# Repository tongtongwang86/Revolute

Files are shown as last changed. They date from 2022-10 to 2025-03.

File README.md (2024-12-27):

# Revolute
- nRF52833 Based Scroll wheel dial
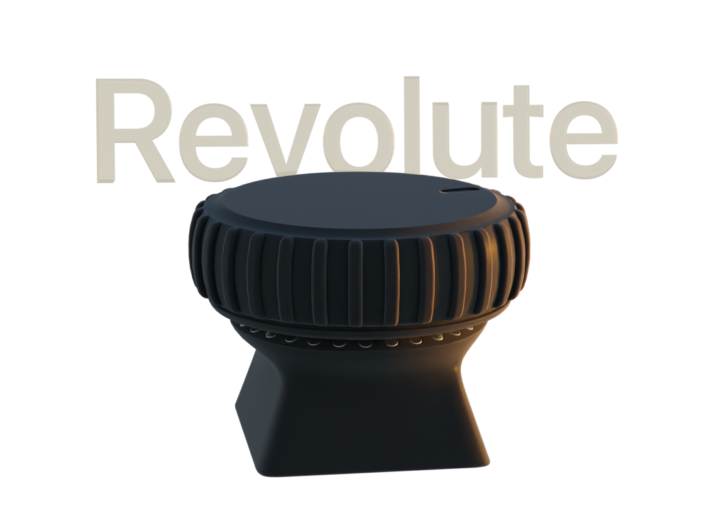
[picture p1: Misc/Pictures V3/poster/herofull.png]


<p align="center">
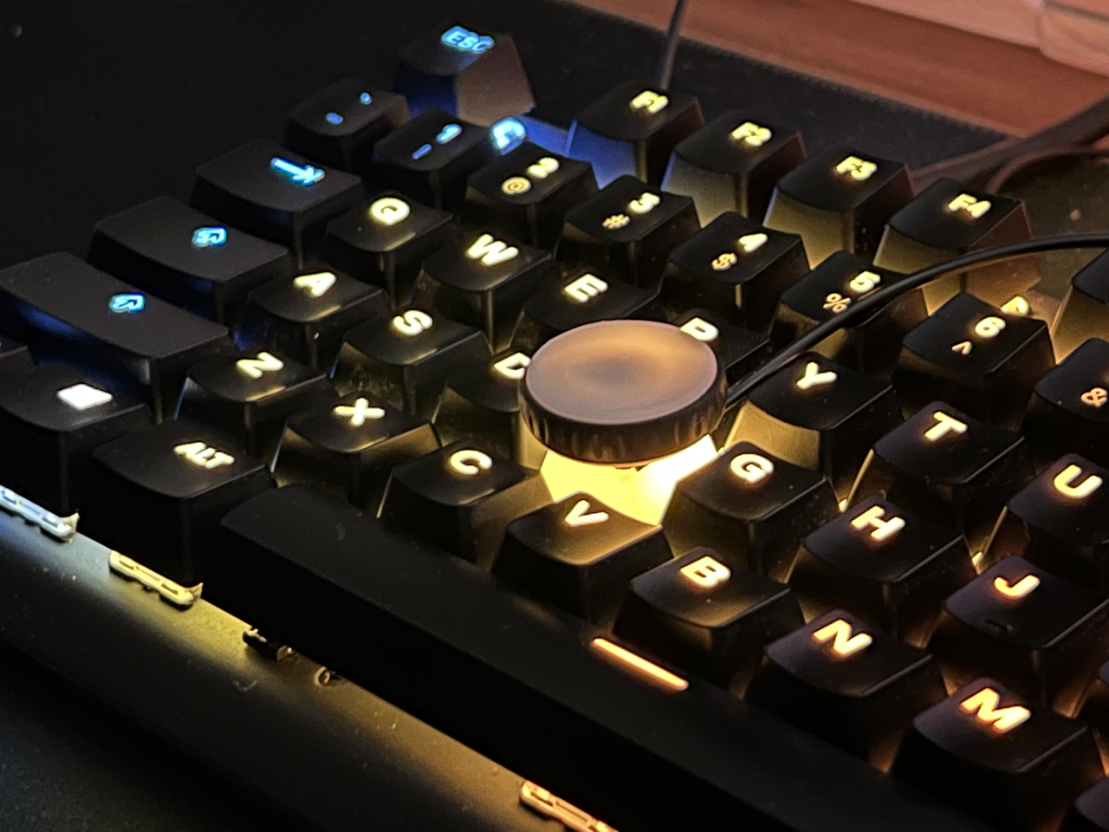
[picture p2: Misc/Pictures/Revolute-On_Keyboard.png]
    
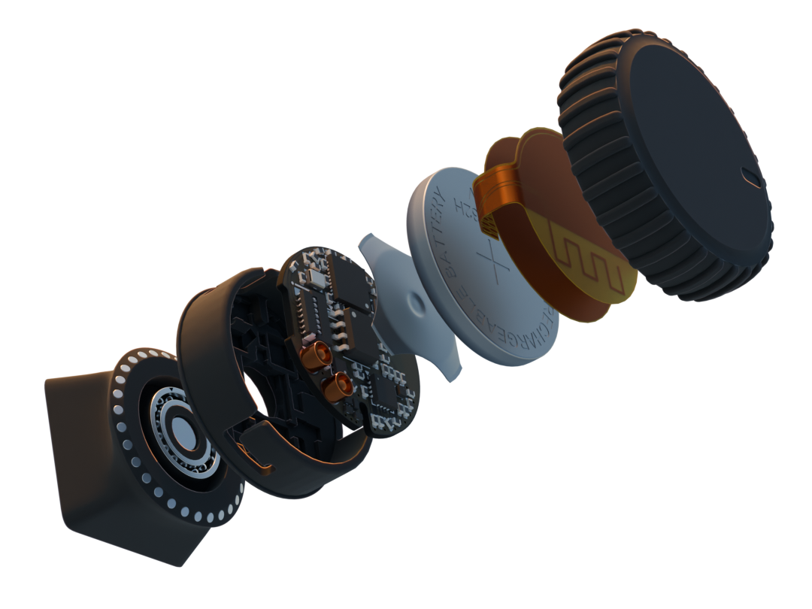
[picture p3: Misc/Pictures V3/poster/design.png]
    
</p>

## Introducing Revolute
 <a href="https://tongtonginc.com/revolute">Visit the product page website (Faster loading time, Interactive 3D Models, Demo Videos)</a>

### The Revolute is a scroll wheel/dial that aims to revolutionize the way we interact with complex software applications.

- Revolute currently simulate keyboard inputs, consumer controlls, mouse inputs.

- the actions and sensitivity of the wheel can be configured through the revolute configurator app that will be available for iOS, Macos and Windows devices that have bluetooth support.

- Configuratios done on revolute is persistently stored on device, which means that revolute can work on any device with Bluetooth and HID support.

- Revolute has a number of use cases and is not limited to: scrubbing through a timeline in a video editing app, changing the brush size in 3D/2D painting, smooth scrolling, volume controll, brightness control, media playback control, quickly pressing keys in short successions within games. if you get two you can bind each revolute axis to x and y of the cursor, making a etch a sketch

- Gamepad emulation is currently in development, which will allow you to use revolute within a wide range of mobile and console games.

## How the Revolute works

### Rotational inputs
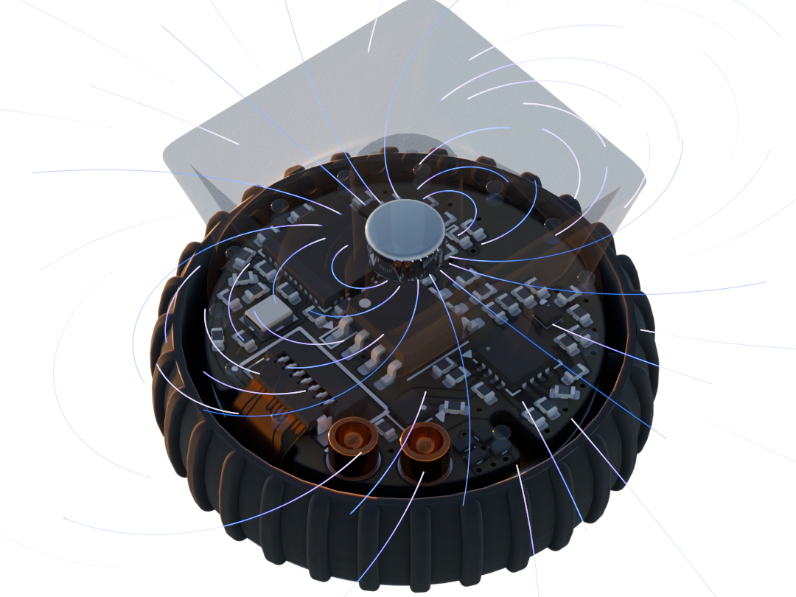
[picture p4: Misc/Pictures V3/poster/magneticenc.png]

- Revolute has gone through a number of iterations and currently uses the AS5600 magnetic encoder. It recordes the angle of a diametric magnet embedded within the base of the revolute, which the SoC will process and send bluetooth reports to the host device.

### BLE connection
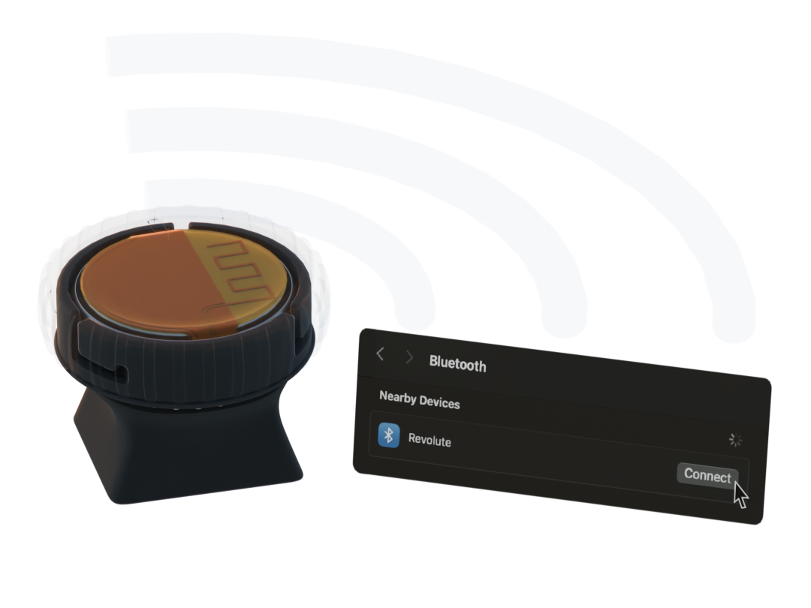
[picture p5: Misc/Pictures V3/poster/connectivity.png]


- Using BLE wireless connection we can have the Revolute connected to devices such as your computer, phone, or tablet using bluetooth. 
- By using the nRF52833 SoC and Zephyr RTOS, the Revolute is designed to maximize its power efficiency for bluetooth functionalities.

### Central button
- By pressing down on the Revolute, it powers on the device.
- After powering on the device, the button can also be configured to other actions based on your configurations
- Power it off by pressing and holding down on the button.

### Configuration
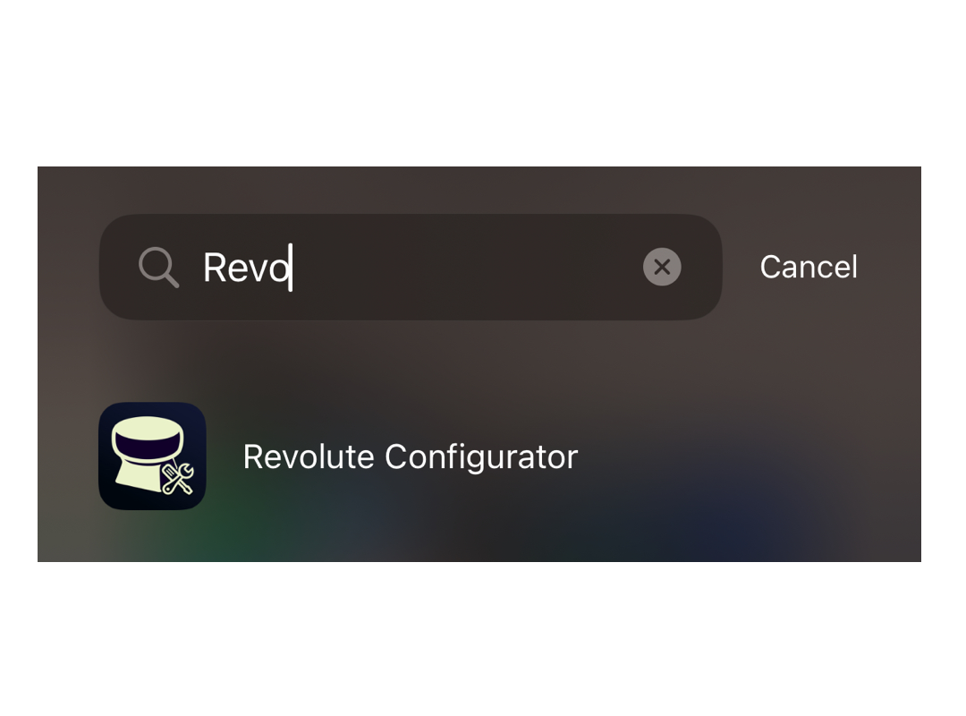
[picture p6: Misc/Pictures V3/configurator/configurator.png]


- As mentioned before, the Revolute's functionalities can be configured through the Revolute Configuration app that is currently in development
- Once you have made your changes to our configurations, they are then sent to the Revolute over bluetooth and stored locally on the SoC. allowing you to use the same configurations across different devices.

### Accessories 
- Revolute has a range of existing accessories that allow you to use it within different use cases

- Key attachment 
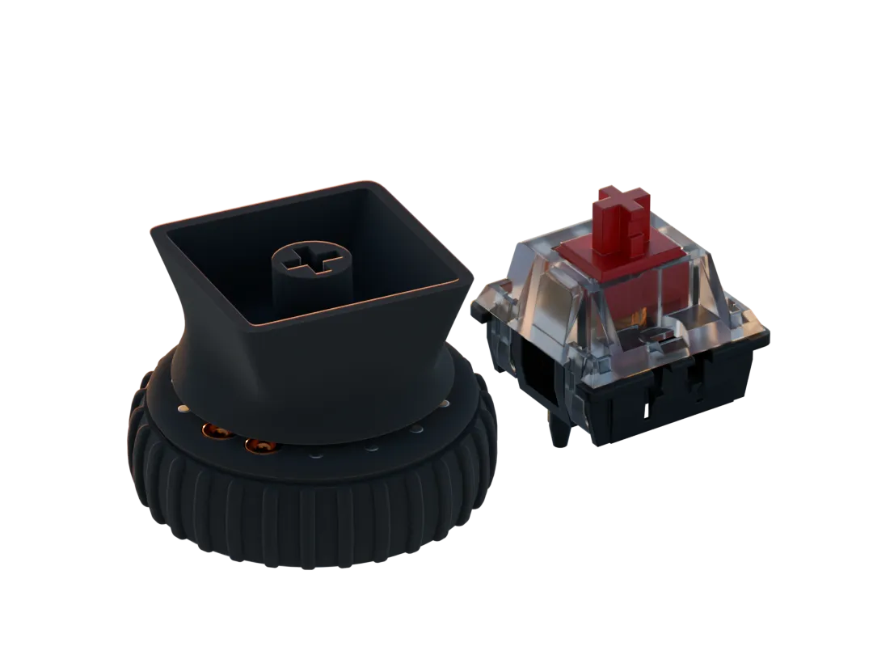
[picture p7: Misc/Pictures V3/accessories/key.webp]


- Adhesive/magnetic attachment
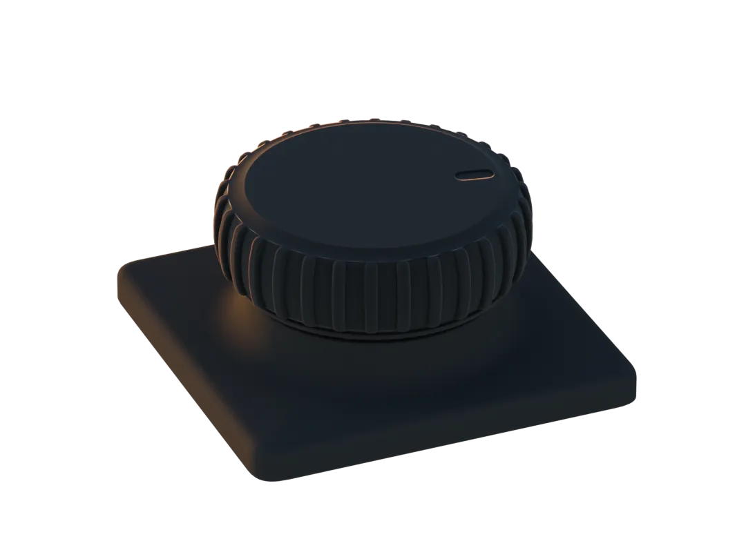
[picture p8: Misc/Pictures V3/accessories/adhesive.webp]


- Phone attachment 
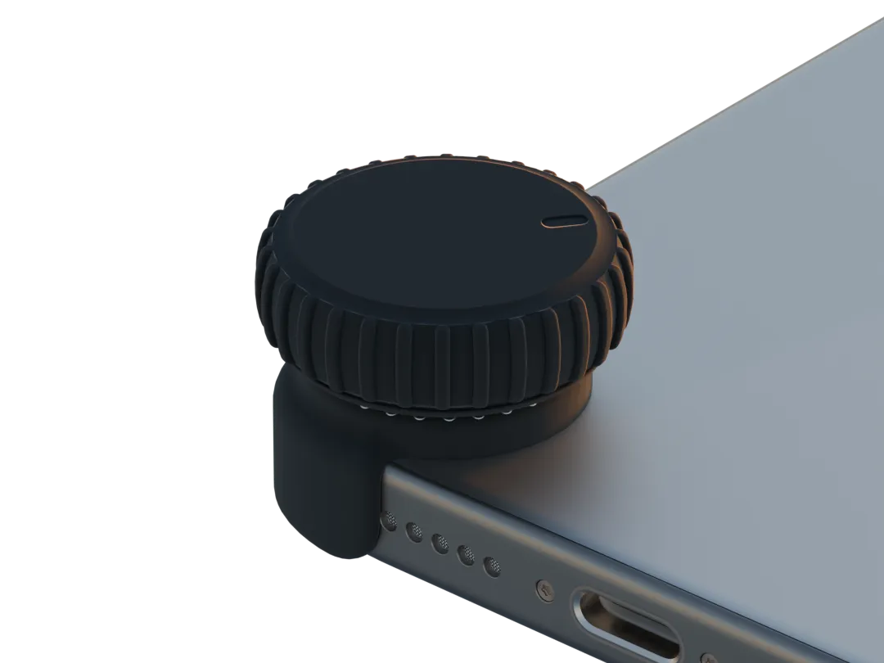
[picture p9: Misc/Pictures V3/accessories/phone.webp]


- Revo-Pod charges the revolute and is a place to store your attachments.
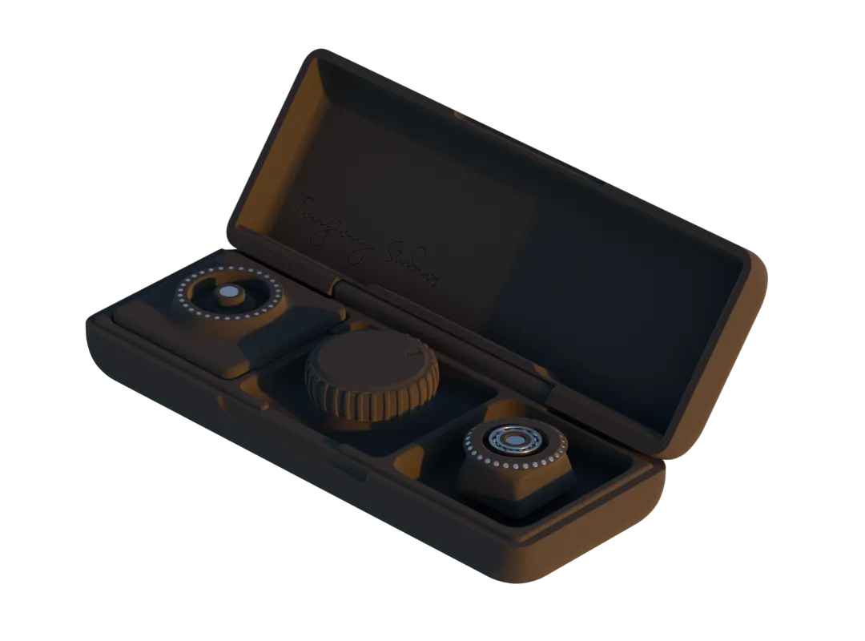
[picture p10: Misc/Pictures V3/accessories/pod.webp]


- The attachment can be hot swapped with a common bearing interface.
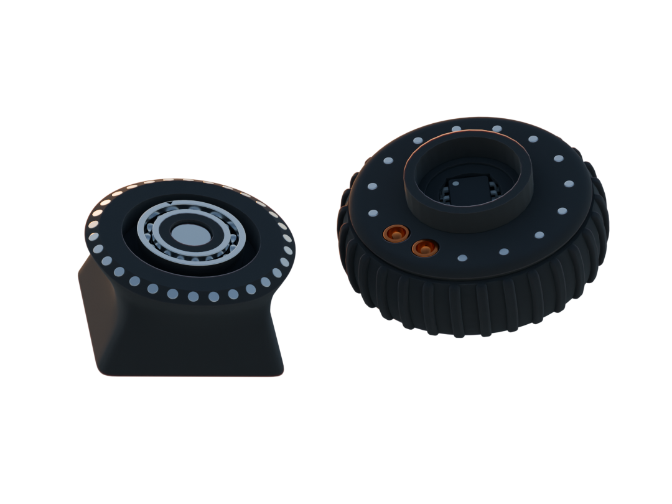
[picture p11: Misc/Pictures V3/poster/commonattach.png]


### Charging and Battery Replacement
- For this device to be wireless, the Revolute is comprised of a 70Mah li-Ion rechargable coin cell battery (LIR2032H)
- The Revolute uses the BQ24075-RGT charger ic and BQ27441-G1 fuel gauge, both by Texas Instruments, for charging, monitoring, and managing the battery that powers the system.
- To charge the Revolute, simply take your Revopod and mount it in the pod and have the two pogopins aligned with the receptors on the wheel.
- To replace the battery, simply flip the Revolute over, press it down until you feel the central button being completely pressed down, and twist it clockwise and you should be able to have the entire Revolute disassembled. From there, simply place a new battery in and reverse the steps of how you disassembled it after your align the cap with the body chassis.

### *Gyro mouse
- With the LSM6DS3 gyroscope accelerometer incorporated in on the Revolute, you can configure it to control the movements of your cursor by moving the Revolute around.
- This feature is still in development and will be finalized shortly in our next firmware updates

## How this repo works
- PCB hardware files are in the folder /Hardware
- 3D printed part files are stored in the folder /3D Prints
- Latest firmware is hosted on the repo <a href="https://github.com/tongtongwang86/revolute-firmware-ci">"revolute-firmware-ci"</a>
- There is also a wired version of the revolute in this repo

## Get your own Revolute
- Revolute is still in development and will be ready soon

 - <a href="https://tongtonginc.com/revolute">For more information head to the product page</a>

- Feel free to DM us if you have any questions or requests

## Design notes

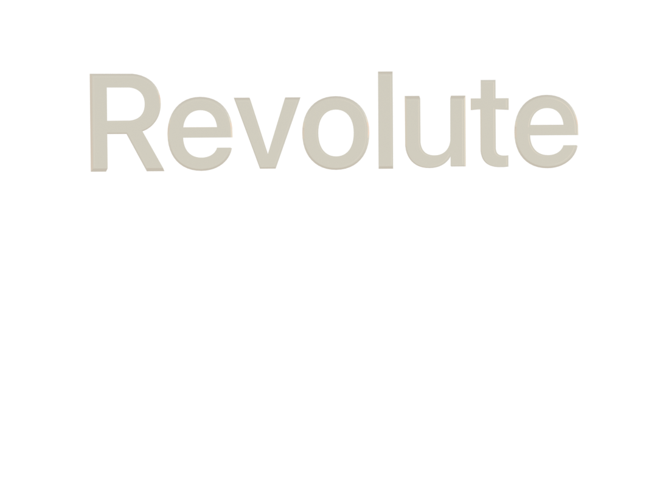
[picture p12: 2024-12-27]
Misc/Pictures V3/poster/hero.png

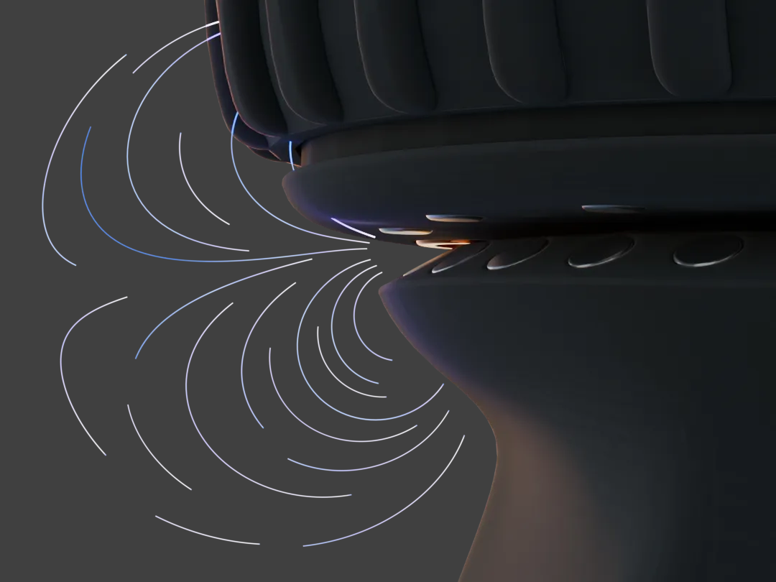
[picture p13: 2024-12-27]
Misc/Pictures V3/poster/magtick.webp

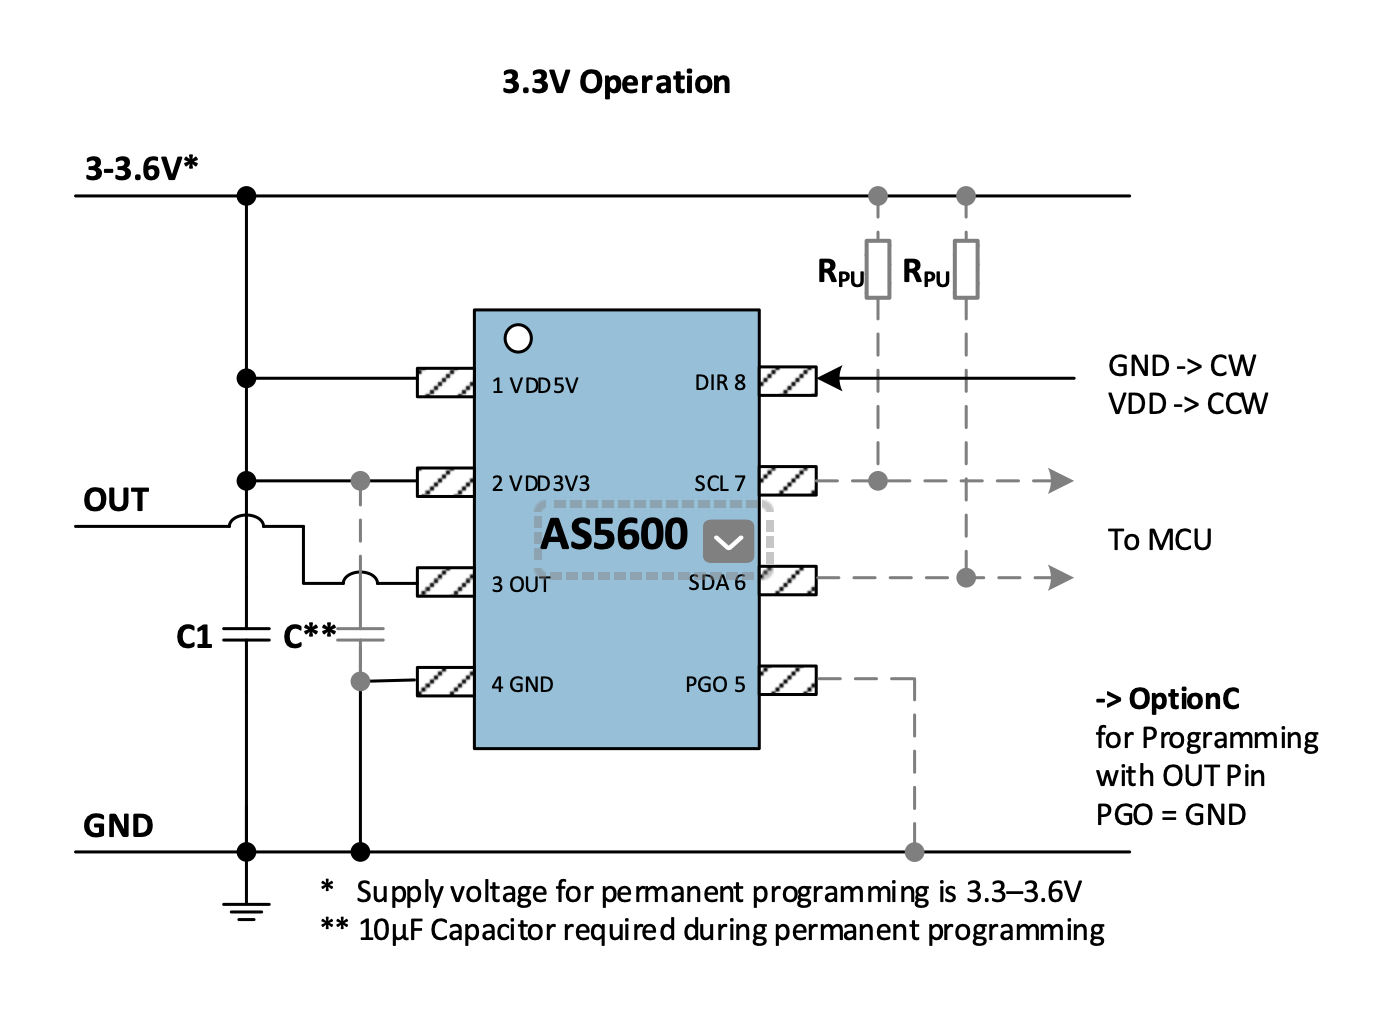
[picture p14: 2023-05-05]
Hardware/Wired/TopPCB/Screenshot 2023-05-04 at 10.35.59 PM.png

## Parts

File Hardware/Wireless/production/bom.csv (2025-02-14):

Designator | Footprint | Quantity | Value | LCSC Part #
D1 | 0402 | 1 | BLUE

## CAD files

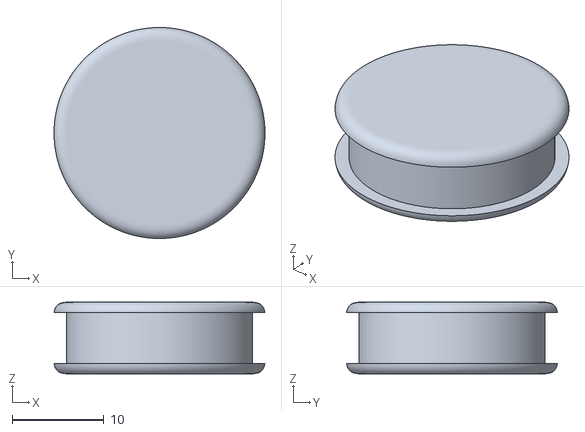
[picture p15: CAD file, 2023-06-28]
3D Prints/V2.1/Cap.stl
23.0 x 23.0 x 7.80

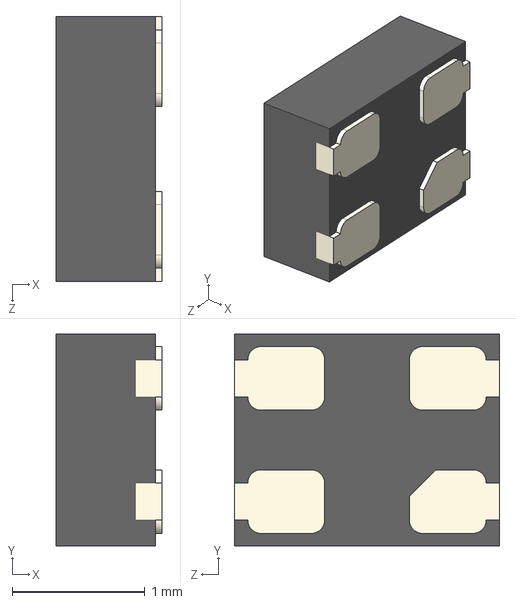
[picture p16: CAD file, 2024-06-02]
Hardware/Debugger/3D/QFN_2016_4pins.STEP
0.8 x 1.60 x 2.00 mm

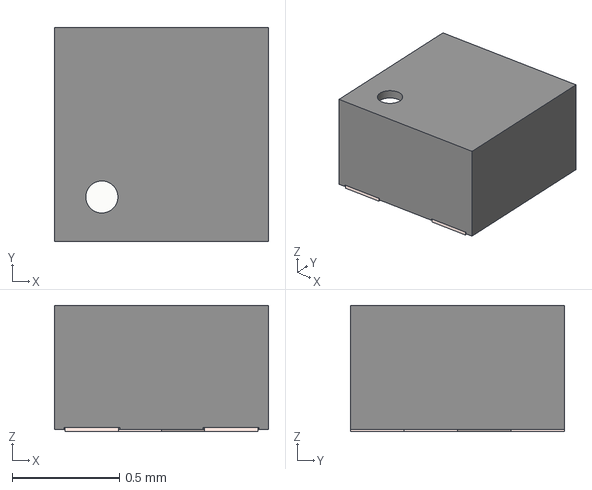
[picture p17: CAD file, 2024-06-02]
Hardware/Debuggerbmp/3D/TDFN-4 v1.step
1.00 x 1.00 x 0.59 mm

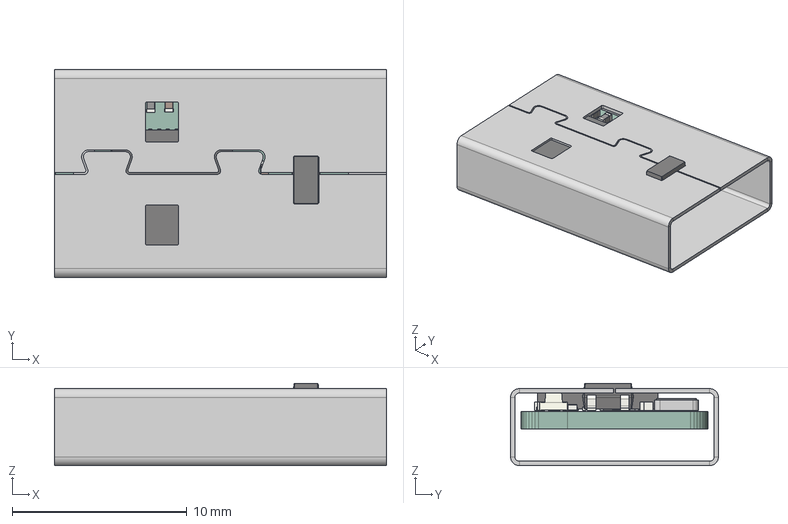
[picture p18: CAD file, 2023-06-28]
Hardware/Wired/MainPCB/revo.step
19.0 x 11.9 x 4.70 mm
PCB

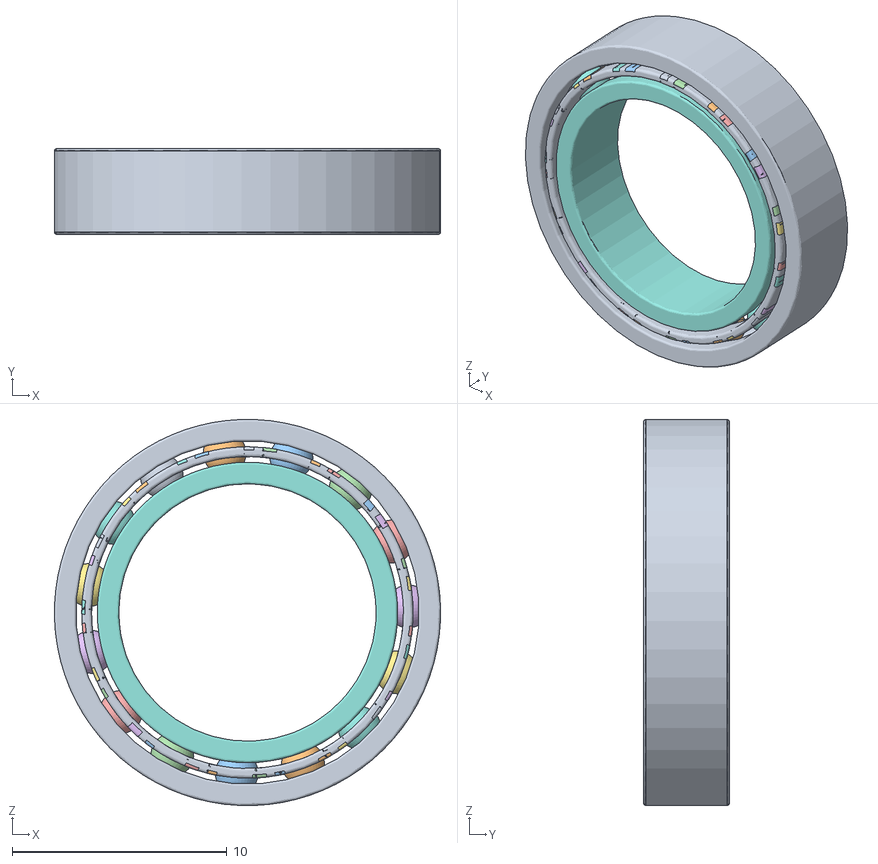
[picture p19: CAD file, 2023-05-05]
Hardware/Wired/TopPCB/Ball_Bearing_Parametric v9 v6.obj
18.0 x 4.00 x 18.0
Outer Ring
Ball Bearings
Ball Bearings (1)
Ball Bearings (2)
Ball Bearings (3)
Ball Bearings (4)
Ball Bearings (5)
Ball Bearings (6)
Ball Bearings (7)
Ball Bearings (8)
Race
Ball race clip outer cylinder
Ball race clip outer cylinder (1)
Ball race clip outer cylinder (1):1
Ball race clip outer cylinder (1) (2)
Ball race clip outer cylinder (1) (3)
Ball race clip outer cylinder (4)
Ball race clip outer cylinder (5)
Ball race clip outer cylinder (1) (6)
Ball race clip outer cylinder (1) (7)
Ball race clip outer cylinder (1) (8)
Ball race clip outer cylinder (1) (9)
Ball race clip outer cylinder (10)
Ball race clip outer cylinder (11)
Ball race clip outer cylinder (12)
Ball race clip outer cylinder (13)
Ball race clip outer cylinder (14)
Ball race clip outer cylinder (1) (1)
Ball race clip outer cylinder (2)
Ball race clip outer cylinder (3)
Ball race clip outer cylinder (1) (4)
Ball race clip outer cylinder (1) (5)
Ball race clip outer cylinder (6)
Ball race clip outer cylinder (7)
Ball race clip outer cylinder (8)
Ball race clip outer cylinder (9)
Ball race clip outer cylinder (1) (10)
Ball race clip outer cylinder (1) (11)
Ball race clip outer cylinder (1) (12)
Ball race clip outer cylinder (1) (13)
Ball race clip outer cylinder (1) (14)
Inner Ring

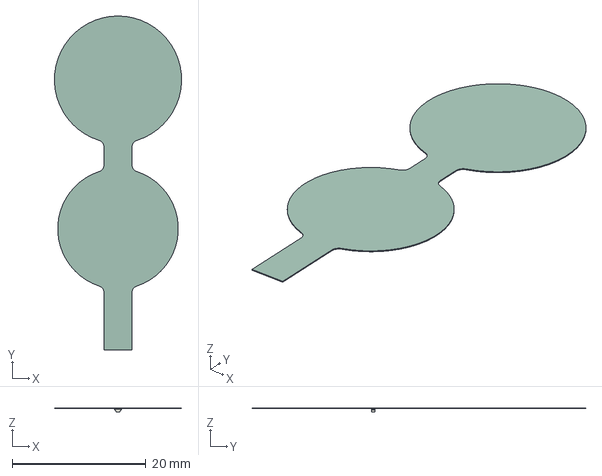
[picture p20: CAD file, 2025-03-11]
Hardware/Wireless/flex3kicad_pcb.step
19.0 x 49.9 x 0.656 mm
LED_0402_1005Metric
_autosave-flex3kicad_pcb_PCB

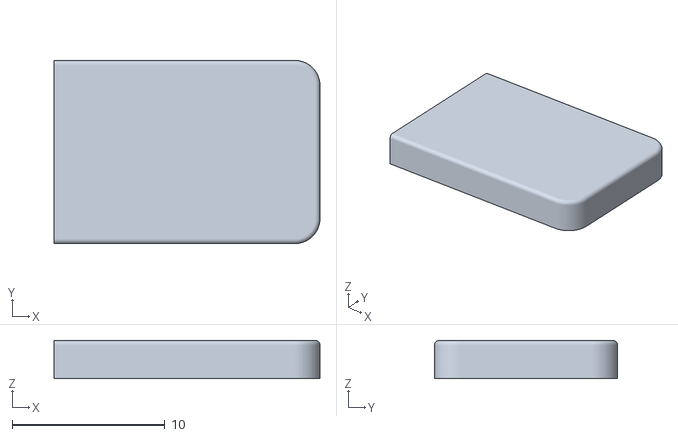
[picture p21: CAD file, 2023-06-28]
3D Prints/V2.1/pcbtray.stl
17.4 x 12.0 x 2.50

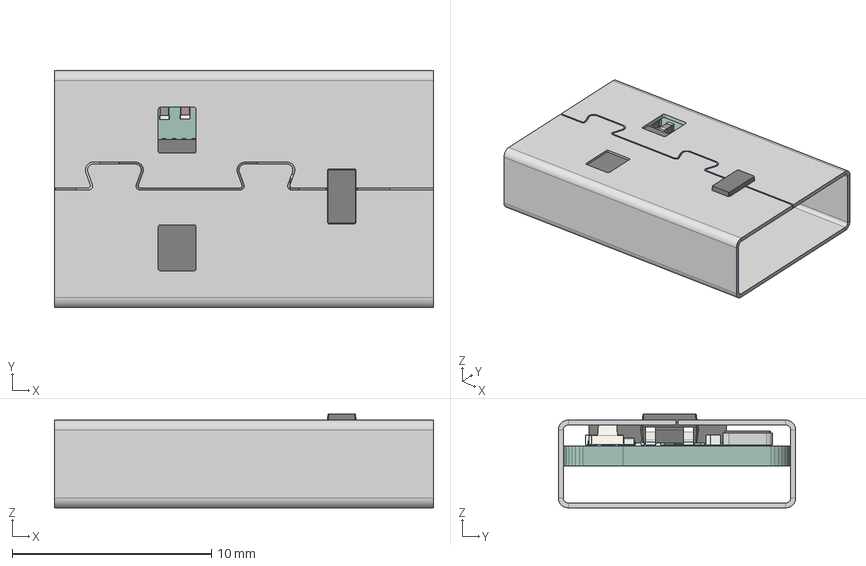
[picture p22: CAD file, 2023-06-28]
Hardware/Wired/MainPCB/rev.step
19.0 x 11.9 x 4.70 mm
PCB

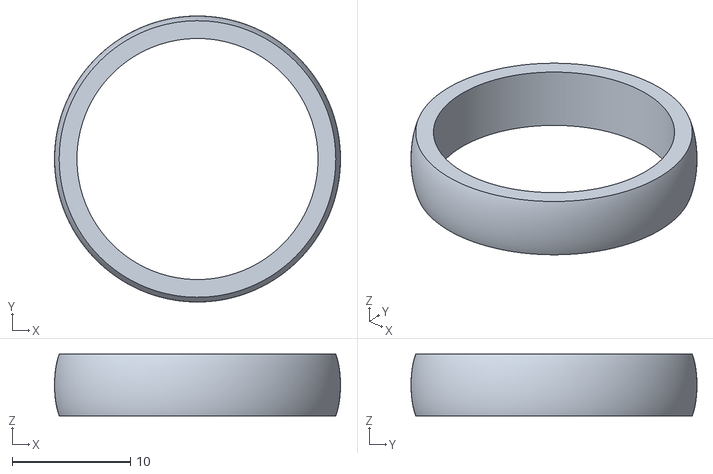
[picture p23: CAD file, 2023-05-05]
Hardware/Wired/TopPCB/rubber.stl
24.2 x 24.2 x 5.20

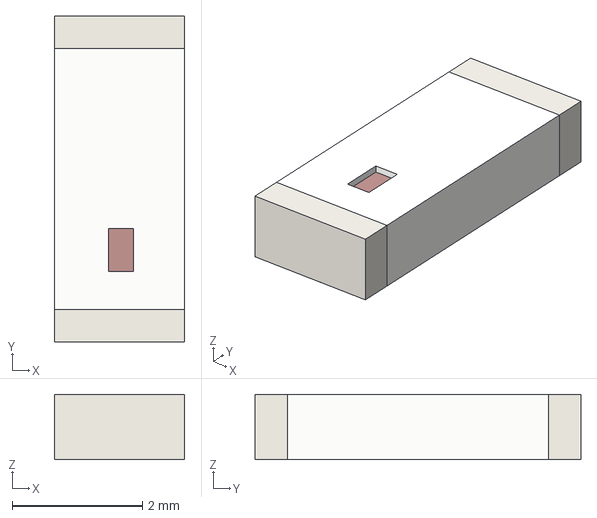
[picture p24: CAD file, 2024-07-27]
Hardware/Wireless/3d/Chip Antenna.step
2.00 x 5.00 x 1.00 mm

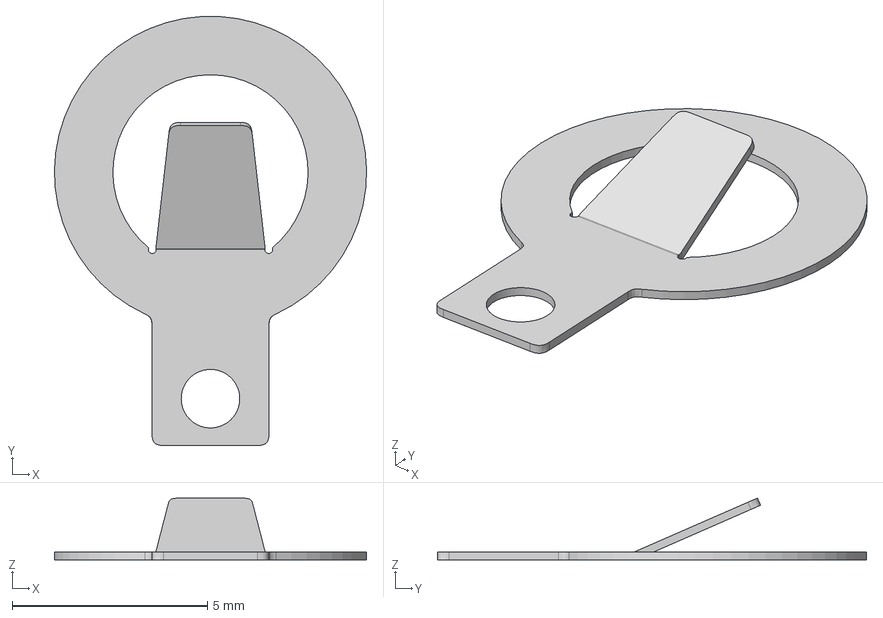
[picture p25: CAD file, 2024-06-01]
Hardware/Debugger/3D/BatteryBase.step
8.00 x 11.0 x 1.59 mm

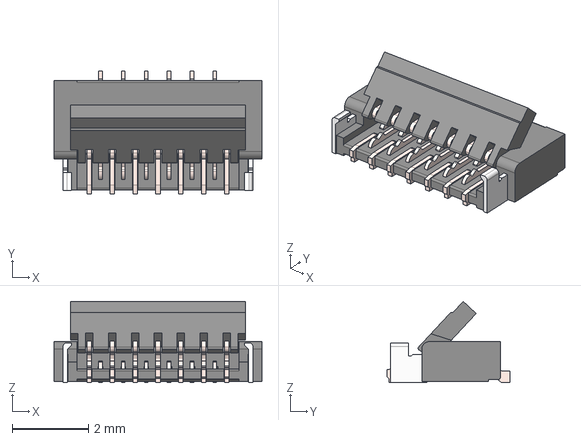
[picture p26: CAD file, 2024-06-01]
Hardware/Debuggerbmp/3D/FPC ZIF.step
5.46 x 3.23 x 2.13 mm

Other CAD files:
3D Prints/V1/Revolute_Wheel.stl
3D Prints/V2/Base.stl
3D Prints/V2/Cap.stl
Hardware/Debugger/3D/256Mbit GD25Q.step
Hardware/Debugger/3D/32MHZ Clock v1.step
Hardware/Debugger/3D/APDS-9960.step
Hardware/Debugger/3D/Antenna.step
Hardware/Debugger/3D/BK13C06-10DP2-0.35V_3D_STP.stp
Hardware/Debugger/3D/BK13C06-10DS2-0.35V_3D_STP.stp
Hardware/Debugger/3D/Battery v2.step
Hardware/Debugger/3D/Battery2 v1.step
Hardware/Debugger/3D/Button.step
Hardware/Debugger/3D/Crystal 2 v0.step
Hardware/Debugger/3D/GateronHotswap v3.step
Hardware/Debugger/3D/Humidity.step
Hardware/Debugger/3D/Inductor v1.step
Hardware/Debugger/3D/KailhChocV2.step
Hardware/Debugger/3D/LedV2 v4.step
Hardware/Debugger/3D/NRF52832-CIAA-R.step
Hardware/Debugger/3D/Pdmmic.step
Hardware/Debugger/3D/SW_Hotswap_Kailh_Choc_v1.stp
Hardware/Debugger/3D/USB - C inboard.step
Hardware/Debugger/3D/USB2 v3.step
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

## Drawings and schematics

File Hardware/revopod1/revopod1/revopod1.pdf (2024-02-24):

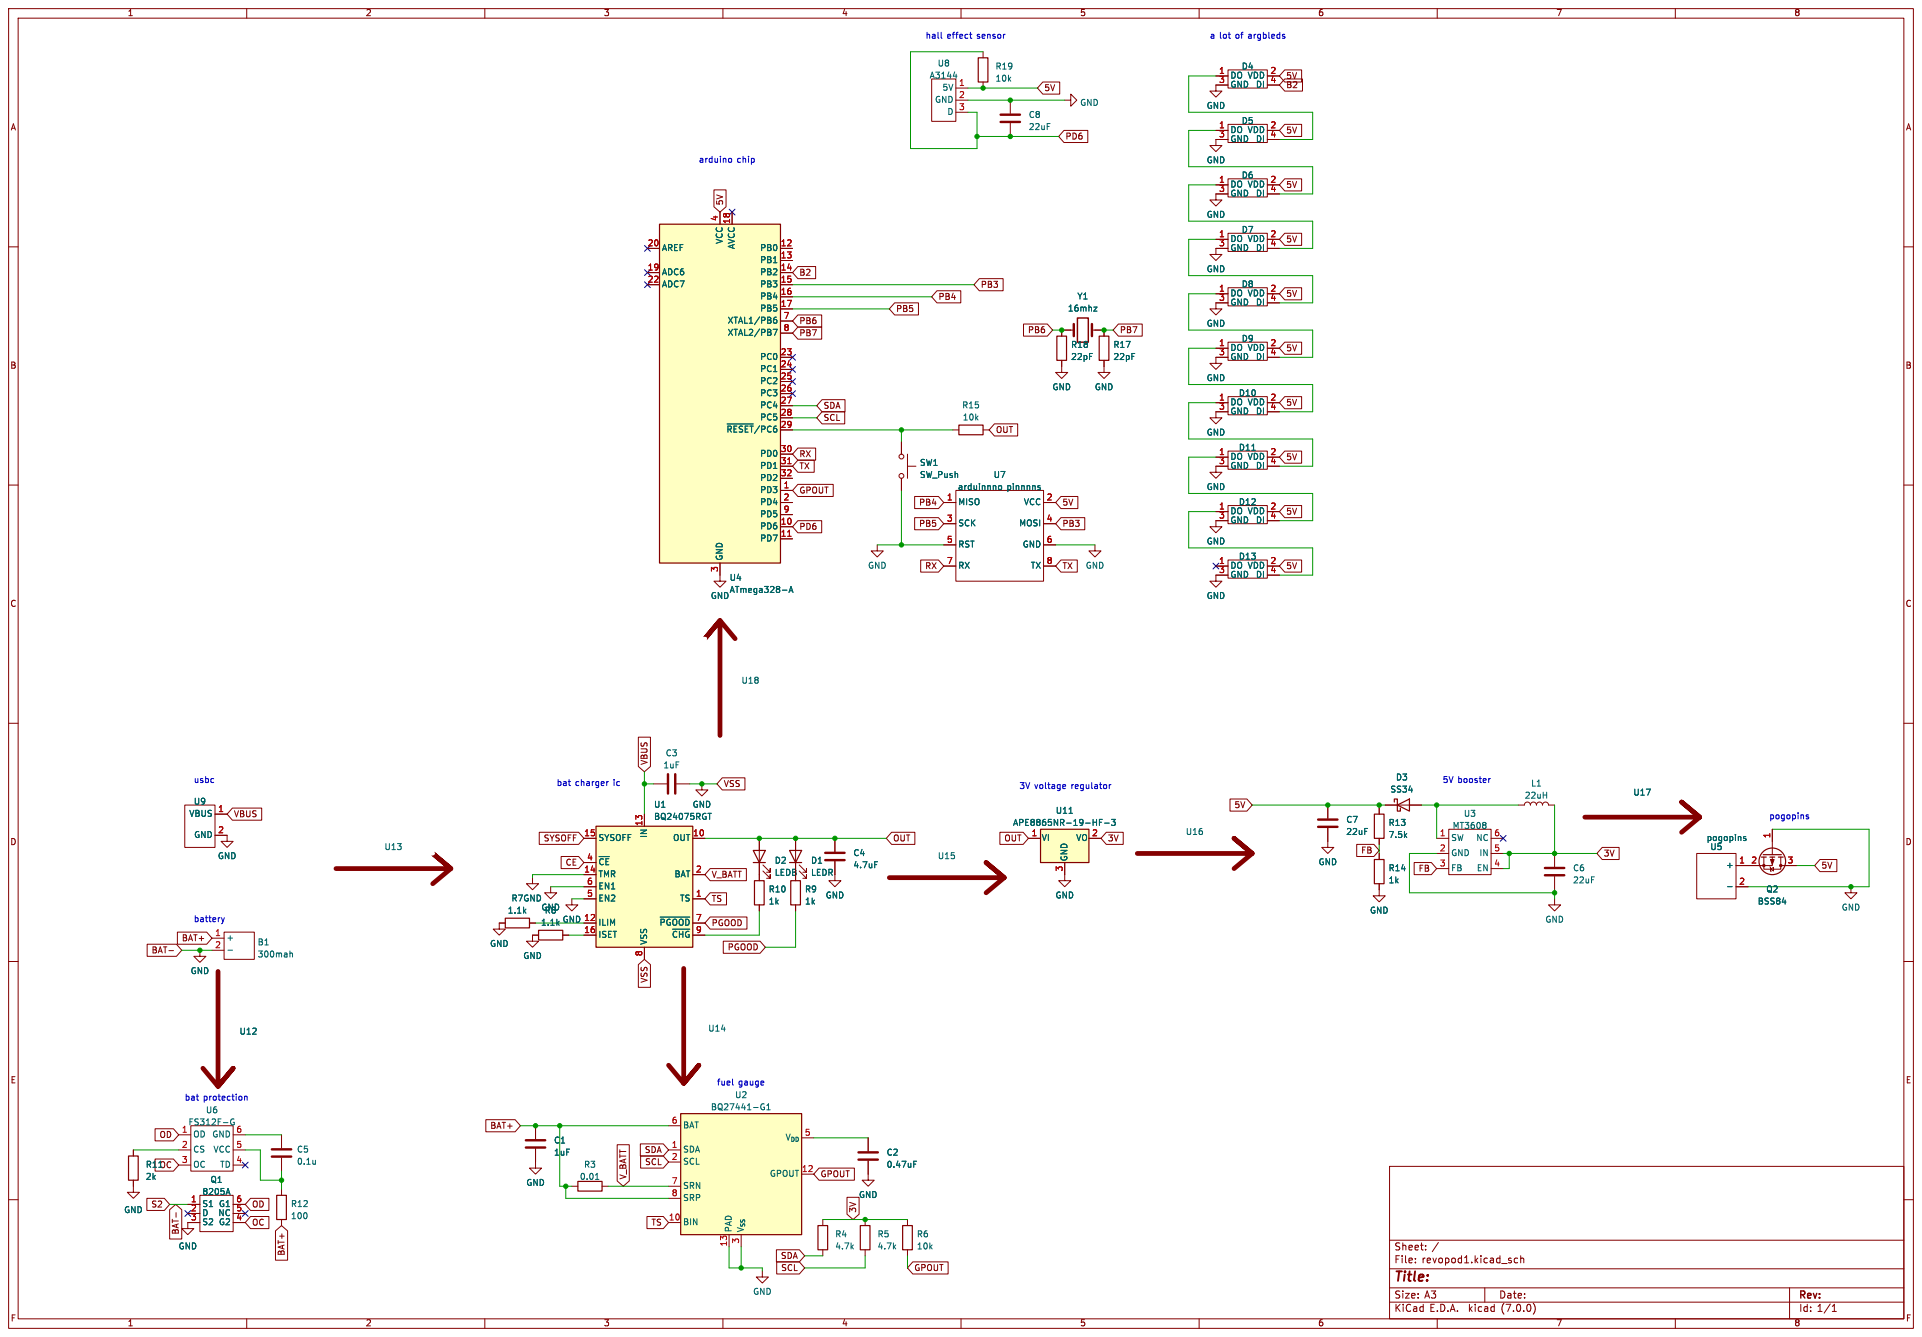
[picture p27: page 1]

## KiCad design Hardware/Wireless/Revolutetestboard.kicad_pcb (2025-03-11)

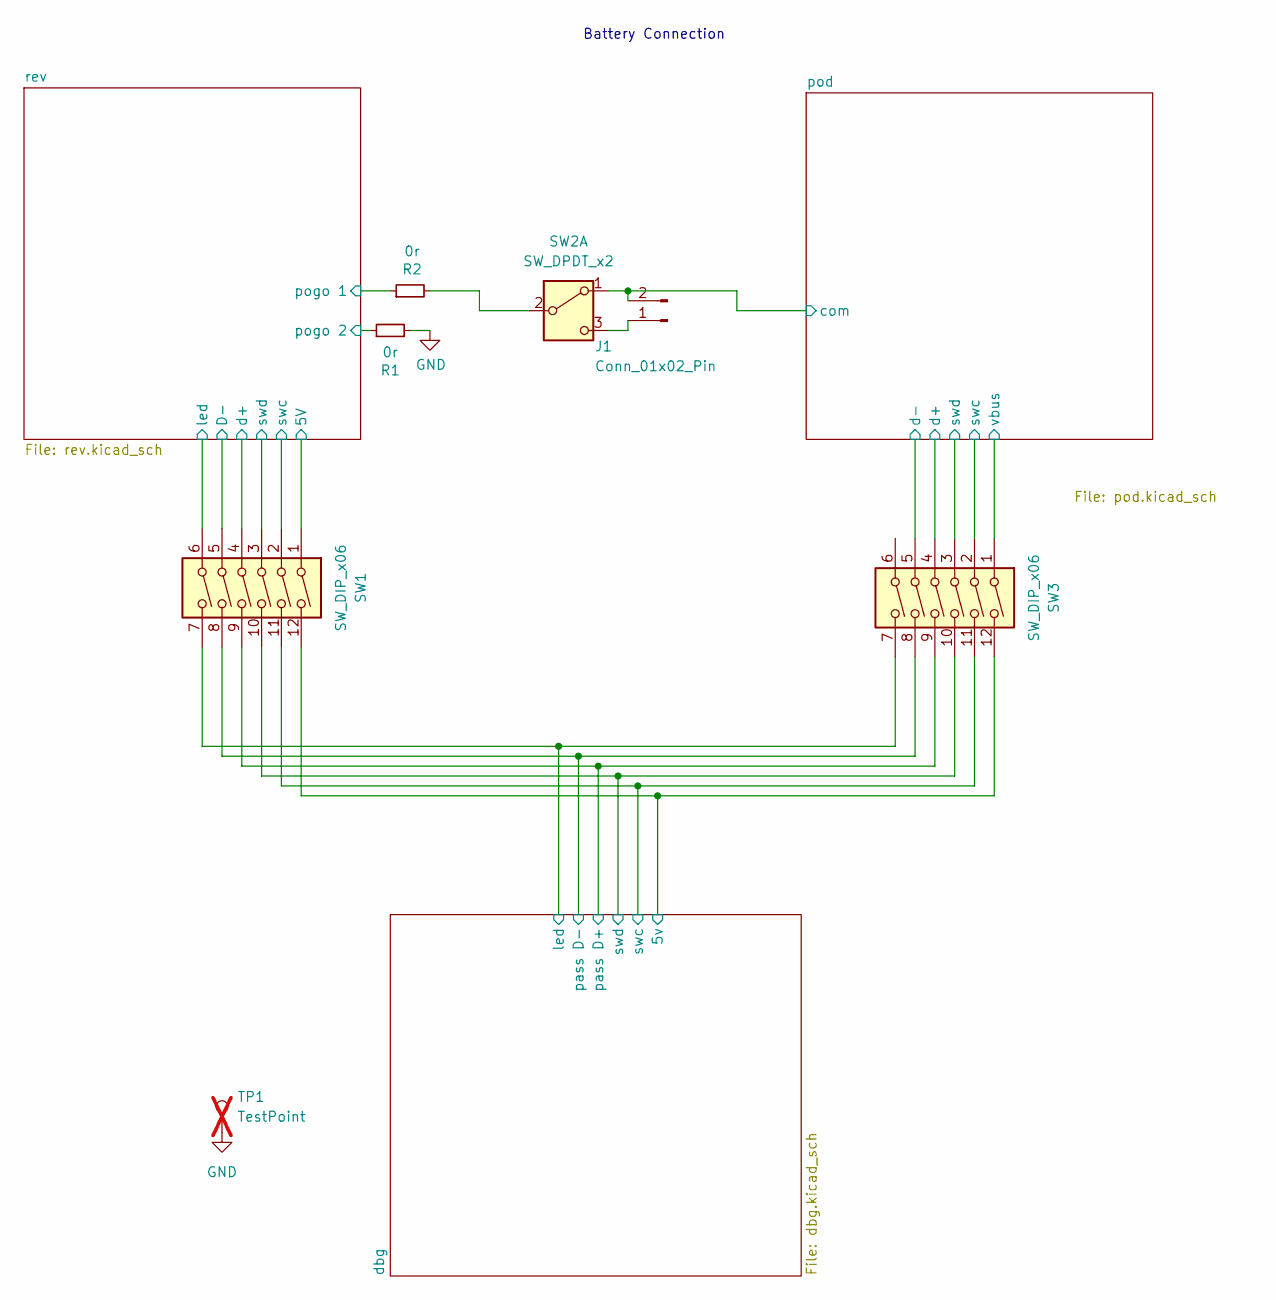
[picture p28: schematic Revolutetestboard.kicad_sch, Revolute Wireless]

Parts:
J1: Conn_01x02_Pin; PinHeader_1x02_P2.54mm_Vertical
R1, R2: 0r; 0402
SW1, SW3: SW_DIP_x06; SW_DIP_SPSTx06_Slide_Copal_CHS-06B_W7.62mm_P1.27mm
SW2: SW_DPDT_x2; MST-12C05 SLIDEBUTTON
TP1: TestPoint; TestPoint_Pad_D1.0mm; not fitted

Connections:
5V(2): SW1.12, SW3.12; also elsewhere on the board
/dbg/USBDM2: SW1.8, SW3.8; also elsewhere on the board
/dbg/USBDP2: SW1.9, SW3.9; also elsewhere on the board
/dbg/swc: SW1.11, SW3.11; also elsewhere on the board
/dbg/swd: SW1.10, SW3.10; also elsewhere on the board
/pod/COM: J1.2, SW2.1 (A); also elsewhere on the board
/pod/D+: SW3.4; also elsewhere on the board
/pod/D-: SW3.5; also elsewhere on the board
/pod/VBUS: SW3.1; also elsewhere on the board
/pod/swc: SW3.2; also elsewhere on the board
/pod/swd: SW3.3; also elsewhere on the board
/rev/+: R1.1; also elsewhere on the board
/rev/-: R2.1; also elsewhere on the board
/rev/D+: SW1.4; also elsewhere on the board
/rev/D-: SW1.5; also elsewhere on the board
/rev/FLEX_LED: SW1.6; also elsewhere on the board
/rev/VBUS: SW1.1; also elsewhere on the board
/rev/swc: SW1.2; also elsewhere on the board
/rev/swd: SW1.3; also elsewhere on the board
GND: R1.2, TP1.1; also elsewhere on the board
unnamed: J1.1, SW2.3 (C)
unnamed: R2.2, SW2.2 (B)
led: SW1.7, SW3.7; also elsewhere on the board

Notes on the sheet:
Battery Connection

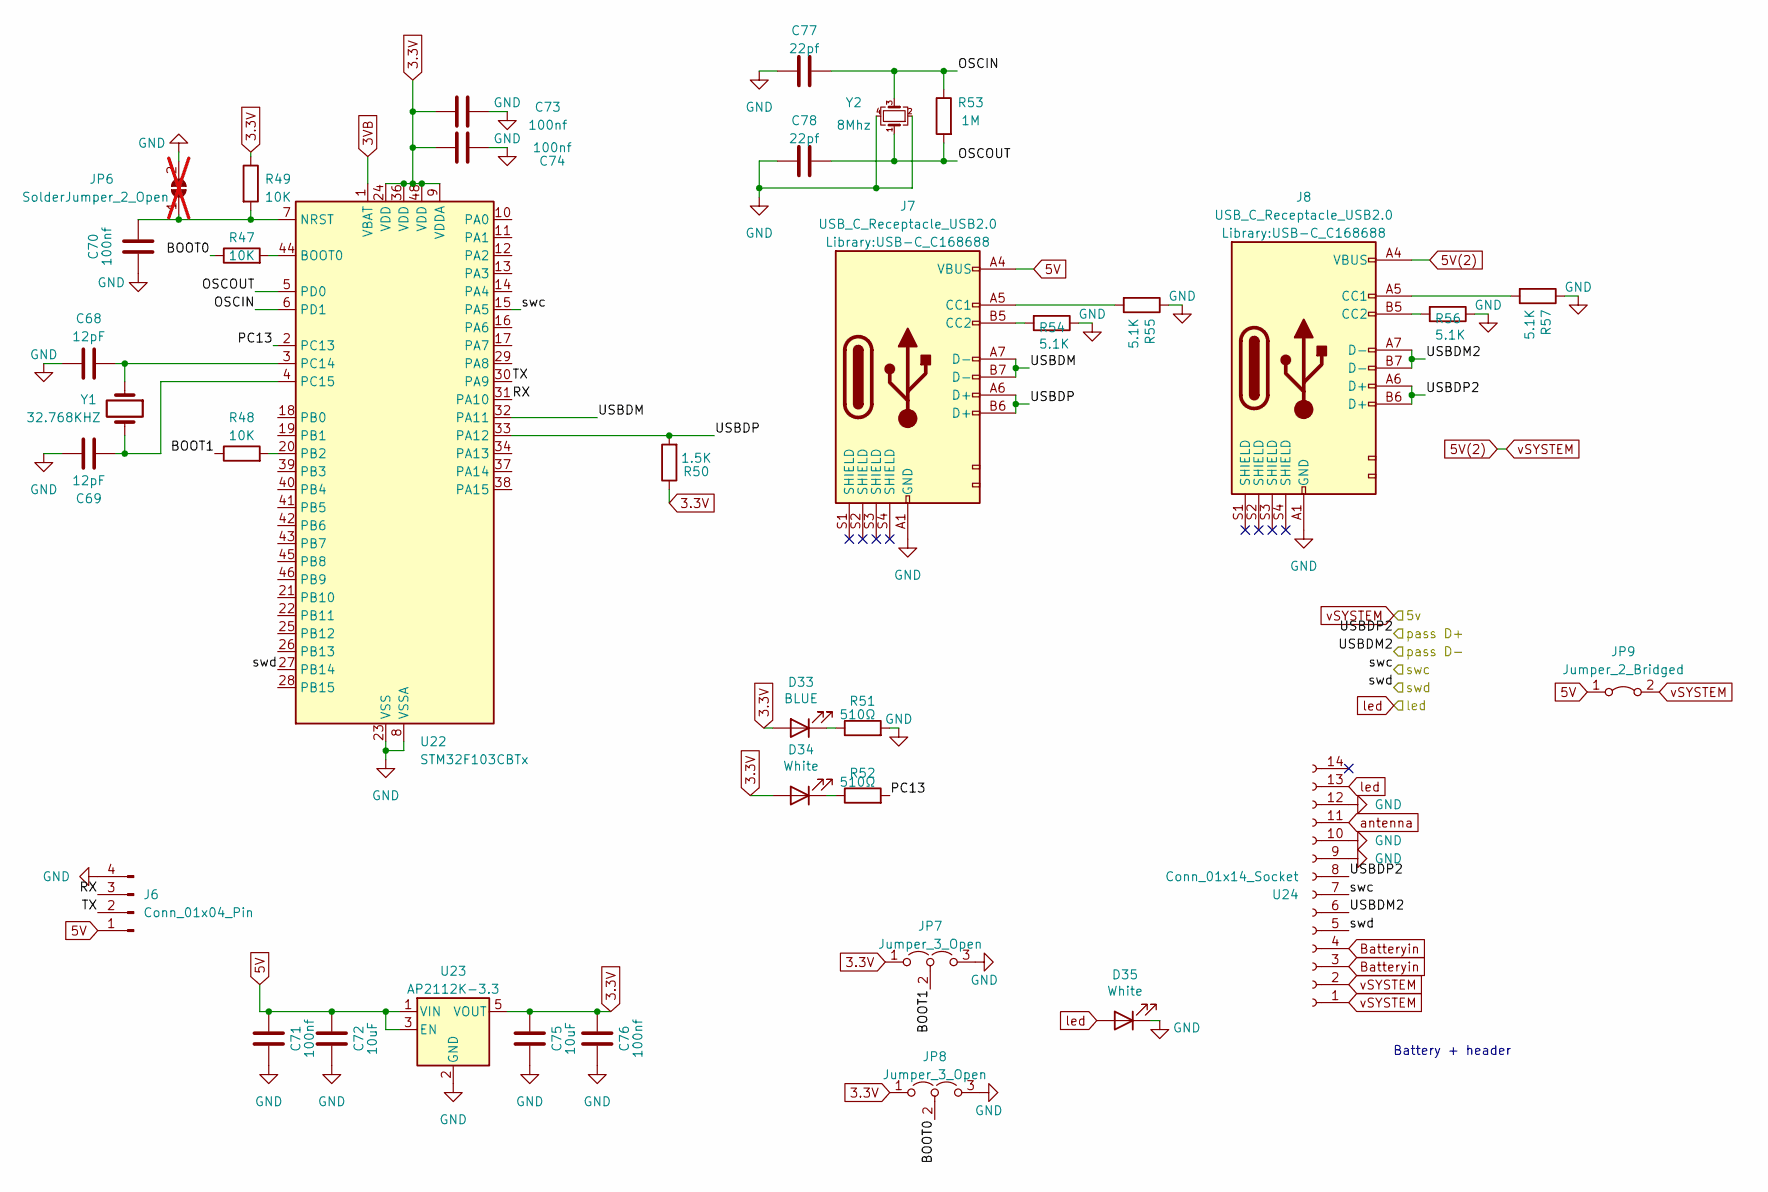
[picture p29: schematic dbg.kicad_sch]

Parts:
C68, C69: 12pF; 0402
C70, C71, C73, C74, C76: 100nf; 0402
C72, C75: 10uF; 0402
C77, C78: 22pf; 0402
D33: BLUE; LED_0402_1005Metric
D34, D35: White; LED_0402_1005Metric
J6: Conn_01x04_Pin; PinHeader_1x04_P1.27mm_Vertical
J7, J8: USB_C_Receptacle_USB2.0; USB-C_C168688
JP6: SolderJumper_2_Open; SolderBridge; not fitted
JP7, JP8: Jumper_3_Open; SolderJumper-3_P1.3mm_Open_RoundedPad1.0x1.5mm
JP9: Jumper_2_Bridged; SolderJumper-2_P1.3mm_Bridged_RoundedPad1.0x1.5mm
R47, R48, R49: 10K; 0402
R50: 1.5K; R_0402_1005Metric
R51, R52: 510Ω; R_0402_1005Metric
R53: 1M; R_0402_1005Metric
R54, R55, R56, R57: 5.1K; R_0402_1005Metric
U22: STM32F103CBTx; LQFP-48_7x7mm_P0.5mm
U23: AP2112K-3.3; SOT-23-5
U24: Conn_01x14_Socket; FPC
Y1: 32.768KHZ; Crystal_SMD_3215-2Pin_3.2x1.5mm
Y2: 8Mhz; Crystal_SMD_3225-4Pin_3.2x2.5mm

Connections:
3.3V: C73.2, C74.2, C75.2, C76.2, D33.2 (A), D34.2 (A), JP7.1 (A), JP8.1 (A), R49.1, R50.1, U22.9 (VDDA), U22.24 (VDD), U22.36 (VDD), U22.48 (VDD), U23.5 (VOUT)
3VB: U22.1 (VBAT)
5V: C71.2, C72.2, J6.1, J7.A4 (VBUS), JP9.1 (A), U23.1 (VIN), U23.3 (EN)
5V(2): J8.A4 (VBUS), JP9.2 (B), U24.1, U24.2; also elsewhere on the board
/dbg/BOOT0: JP8.2 (C), R47.1
/dbg/BOOT1: JP7.2 (C), R48.1
/dbg/OSCIN: C77.2, R53.1, U22.6 (PD1), Y2.3
/dbg/OSCOUT: C78.2, R53.2, U22.5 (PD0), Y2.1
/dbg/PC13: R52.2, U22.2 (PC13)
/dbg/RX: J6.3, U22.31 (PA10)
/dbg/TX: J6.2, U22.30 (PA9)
/dbg/USBDM: J7.A7 (D-), J7.B7 (D-), U22.32 (PA11)
/dbg/USBDM2: J8.A7 (D-), J8.B7 (D-), U24.6; also elsewhere on the board
/dbg/USBDP: J7.A6 (D+), J7.B6 (D+), R50.2, U22.33 (PA12)
/dbg/USBDP2: J8.A6 (D+), J8.B6 (D+), U24.8; also elsewhere on the board
/dbg/swc: U22.15 (PA5), U24.7; also elsewhere on the board
/dbg/swd: U22.27 (PB14), U24.5; also elsewhere on the board
Batteryin: U24.3, U24.4
GND: C68.1, C69.2, C70.1, C71.1, C72.1, C73.1, C74.1, C75.1, C76.1, C77.1, C78.1, D35.1 (K), J6.4, J7.A1 (GND), J8.A1 (GND), JP6.2 (B), JP7.3 (B), JP8.3 (B), R51.2, R54.1, R55.1, R56.1, R57.1, U22.8 (VSSA), U22.23 (VSS), U22.35 (VSS), U22.47 (VSS), U23.2 (GND), U24.9, U24.10, U24.12, Y2.2, Y2.4; also elsewhere on the board
unnamed: D33.1 (K), R51.1
unnamed: D34.1 (K), R52.1
unnamed: J7.A5 (CC1), R55.2
unnamed: J7.B5 (CC2), R54.2
unnamed: J8.A5 (CC1), R57.2
unnamed: J8.B5 (CC2), R56.2
unnamed: C70.2, JP6.1 (A), R49.2, U22.7 (NRST)
unnamed: R47.2, U22.44 (BOOT0)
unnamed: R48.2, U22.20 (PB2)
unnamed: C68.2, U22.3 (PC14), Y1.1
unnamed: C69.1, U22.4 (PC15), Y1.2
antenna: U24.11
led: D35.2 (A), U24.13; also elsewhere on the board

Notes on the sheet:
Battery + header

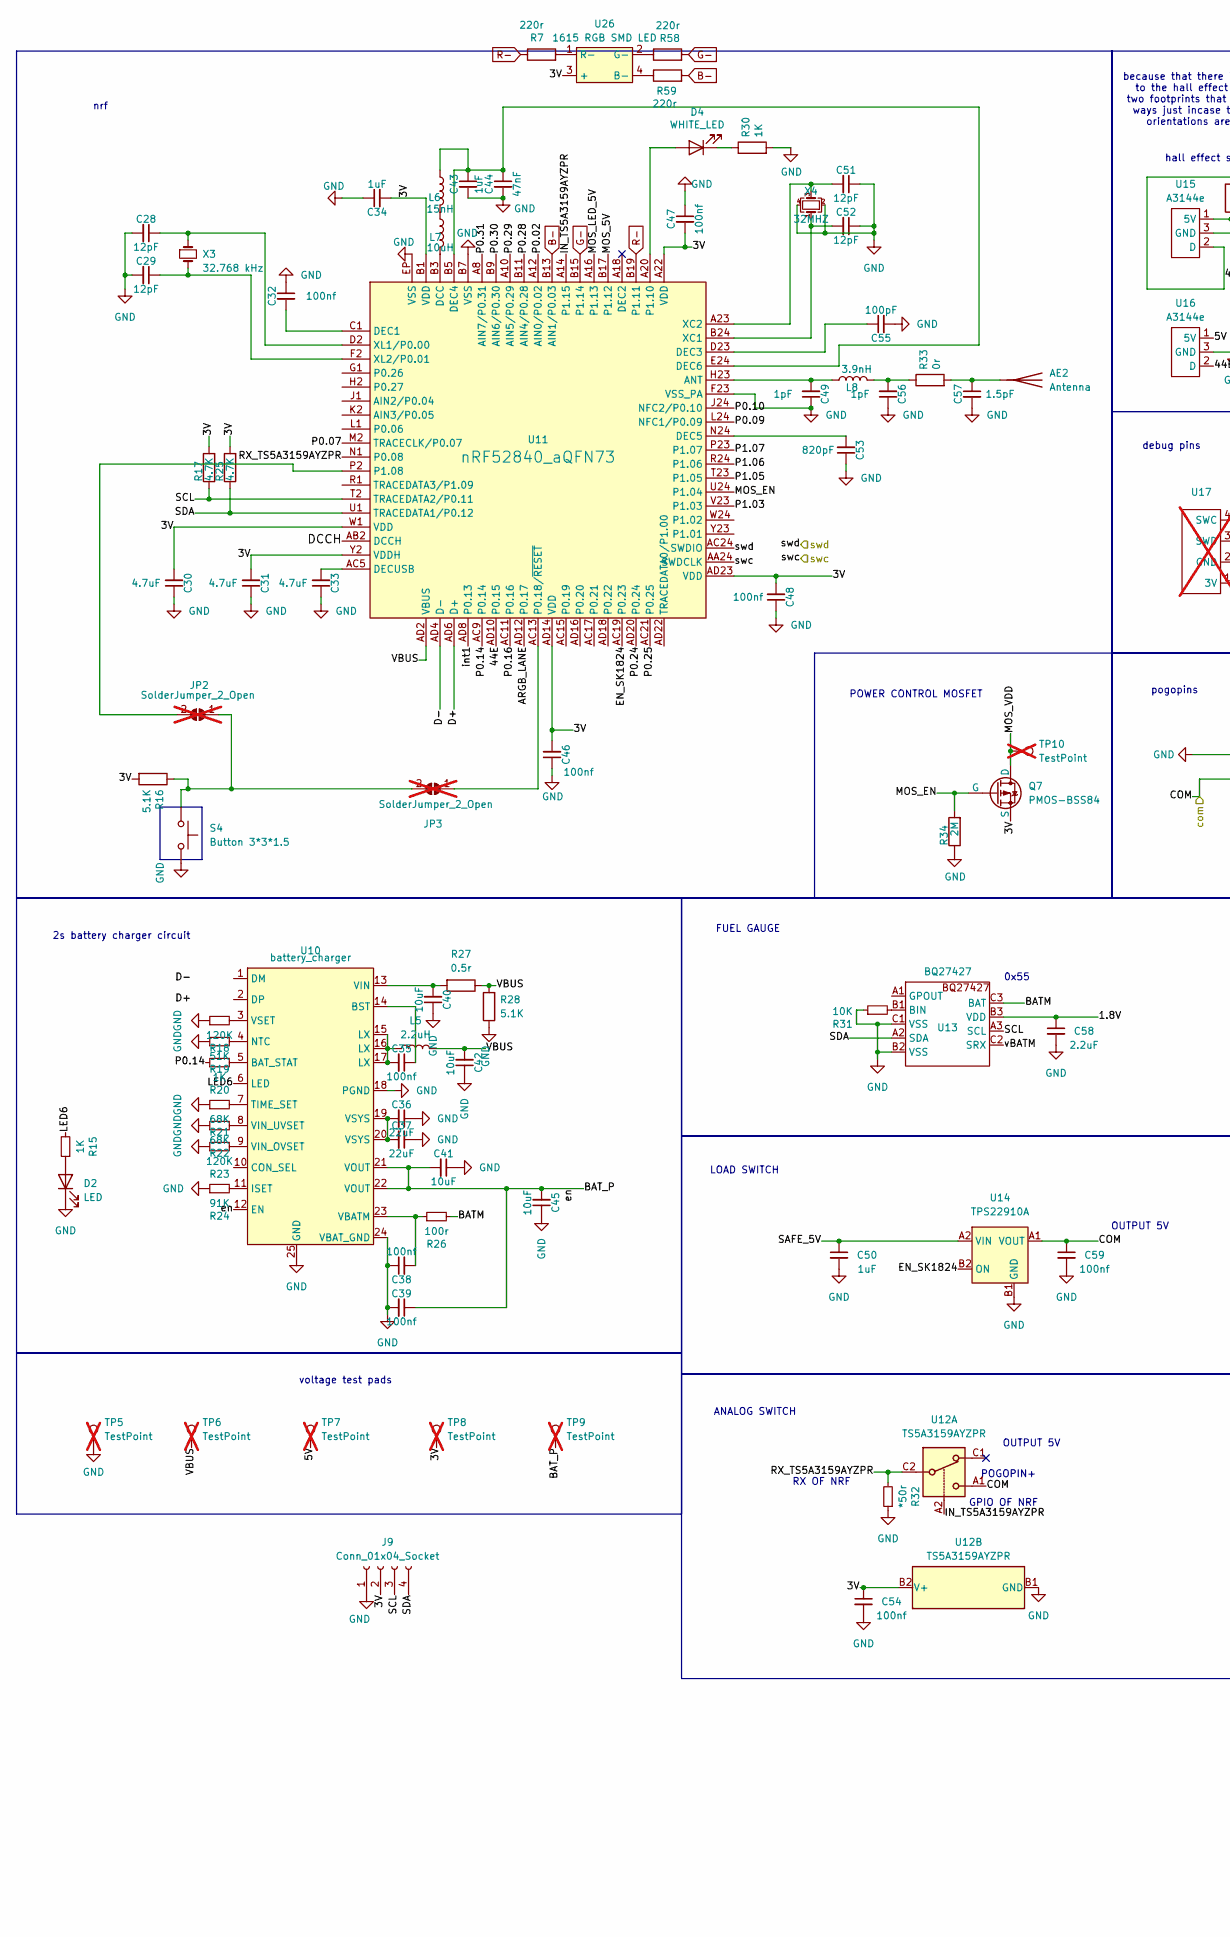
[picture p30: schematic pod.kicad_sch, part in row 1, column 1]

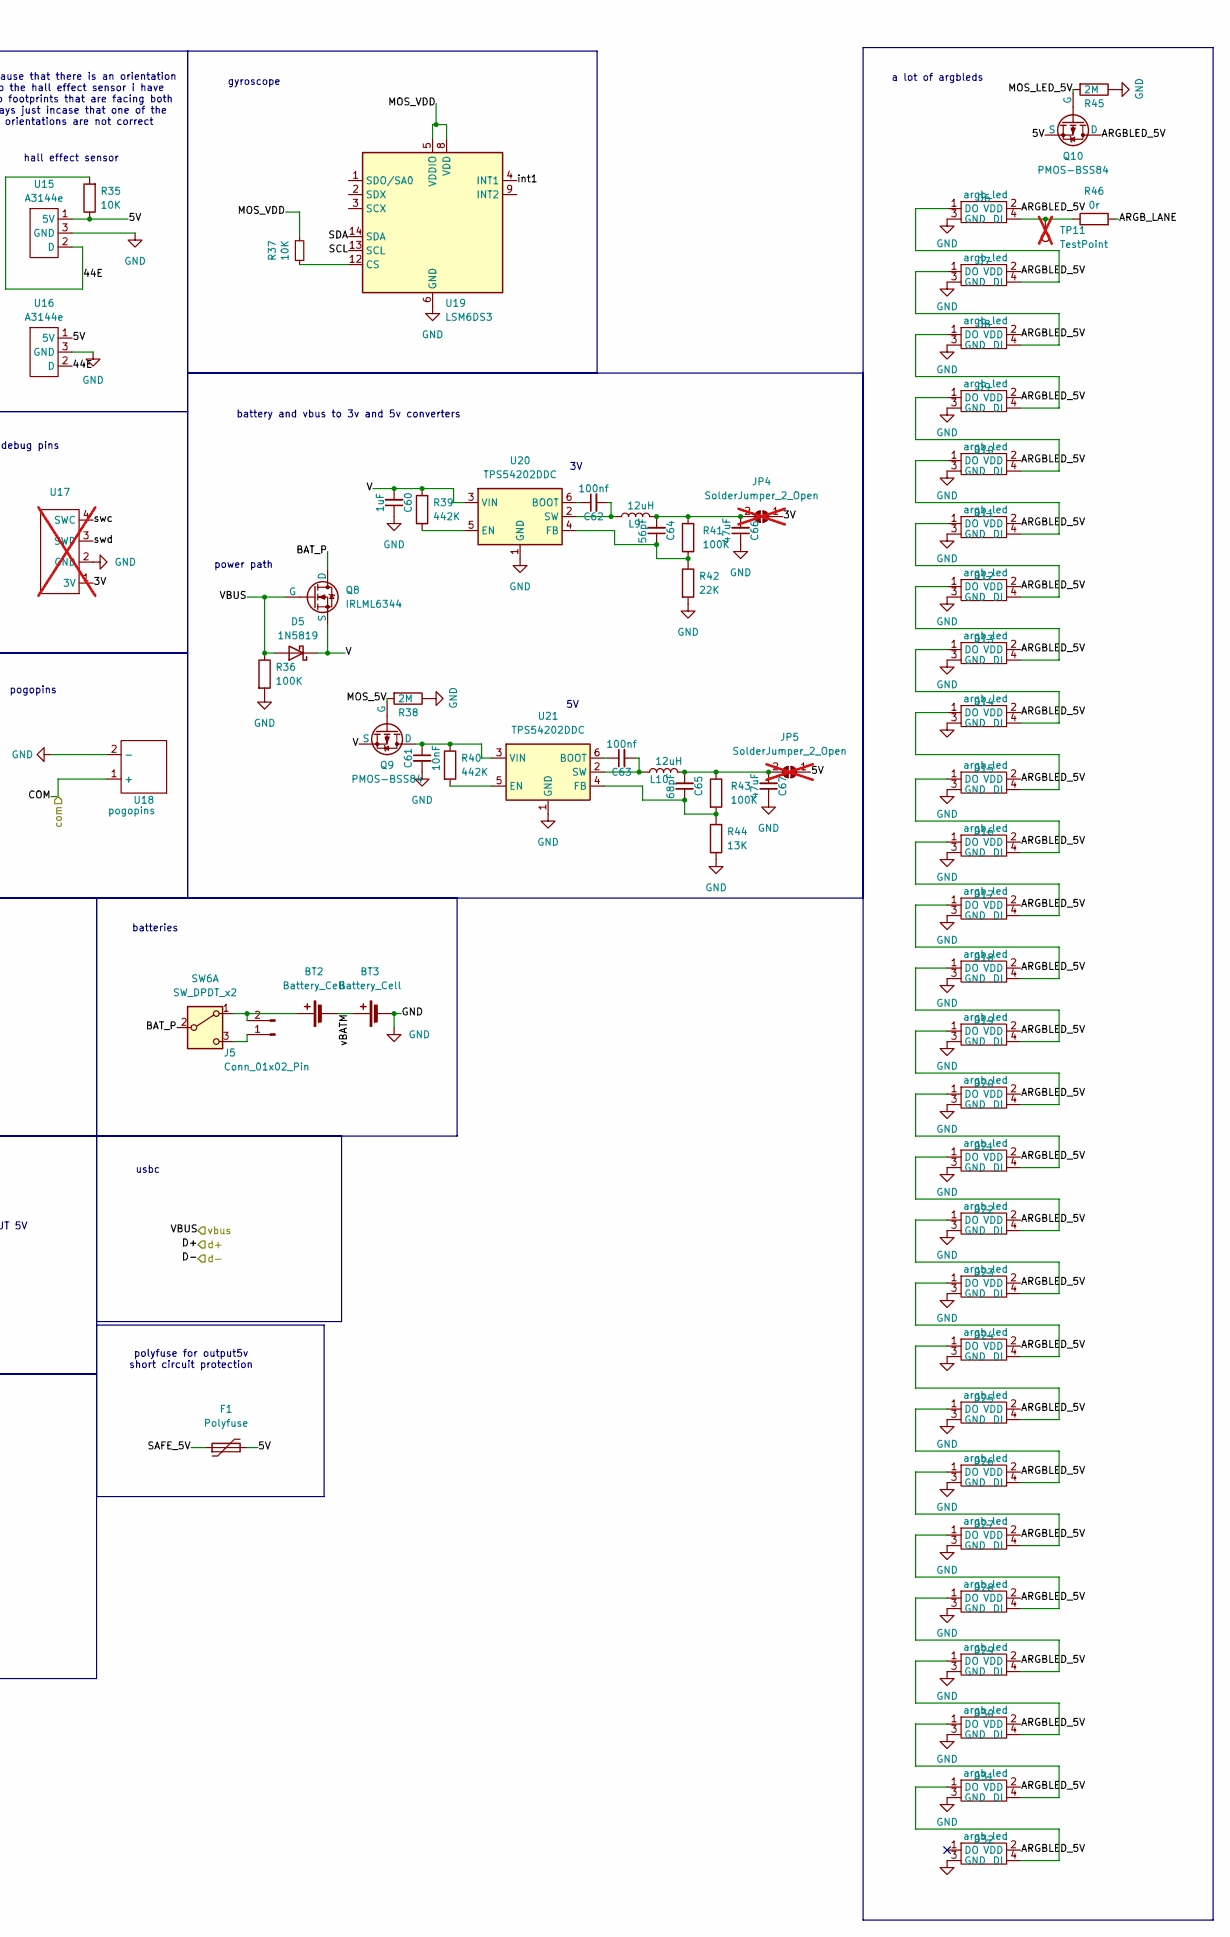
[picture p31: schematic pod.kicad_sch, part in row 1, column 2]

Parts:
AE2: Antenna; 2.4GHz-meander-antenna
BT2, BT3: Battery_Cell; BatteryHolder_Keystone_1057_1x2032
C28, C29, C51, C52: 12pF; 0402
C30, C31, C33: 4.7uF; 0402
C32, C35, C38, C39, C46, C47, C48, C54, C59, C62, C63: 100nf; 0402
C34, C43, C50, C60: 1uF; 0402
C36, C37: 22uF; 0402
C40, C41, C42, C45: 10uF; 0402
C44: 47nF; 0402
C49, C56: 1pF; 0402
C53: 820pF; 0402
C55: 100pF; 0402
C57: 1.5pF; 0402
C58: 2.2uF; 0402
C61: 10nF; 0402
C64: 56pF; 0402
C65: 68pF; 0402
C66, C67: 47uF; 0402
D2: LED; LED_0402_1005Metric
D4: WHITE_LED; LED_0402_1005Metric
D5: 1N5819; D_SOD-323_HandSoldering
D6, D7, D8, D9, D10, D11, D12, D13, D14, D15, D16, D17, D18, D19, D20, D21, D22, D23, D24, D25, D26, D27, D28, D29, D30, D31, D32: argb_led; Led-ARGB
F1: Polyfuse; R_0805_2012Metric
J5: Conn_01x02_Pin; PinHeader_1x02_P2.54mm_Vertical
J9: Conn_01x04_Socket; PinSocket_1x04_P2.54mm_Vertical
JP2, JP3, JP4, JP5: SolderJumper_2_Open; SolderBridge; not fitted
L5: 2.2uH; L_Chilisin_BMRA00050520
L6: 15nH; 0402
L7: 10uH; 0402
L8: 3.9nH; L_0402_1005Metric
L9, L10: 12uH; L_0603_1608Metric
Q7, Q9, Q10: PMOS-BSS84; SOT-23-3
Q8: IRLML6344; TSOT-23
R7, R58, R59: 220r; R_0402_1005Metric
R15, R20, R30: 1K; R_0402_1005Metric
R16, R28: 5.1K; R_0402_1005Metric
R17, R25: 4.7K; 0402
R18, R23: 120K; R_0402_1005Metric
R19: 51K; R_0402_1005Metric
R21, R22: 68K; R_0402_1005Metric
R24: 91K; R_0402_1005Metric
R26: 100r; R_0402_1005Metric
R27: 0.5r; R_0402_1005Metric
R31: 10K; 0402
R32: *50r; R_0402_1005Metric
R33, R46: 0r; 0402
R34, R38, R45: 2M; 0402
R35, R37: 10K; R_0402_1005Metric
R36, R41, R43: 100K; R_0402_1005Metric
R39, R40: 442K; R_0402_1005Metric
R42: 22K; R_0402_1005Metric
R44: 13K; R_0402_1005Metric
S4: Button 3*3*1.5; button 3x3
SW6: SW_DPDT_x2; MST-12C05 SLIDEBUTTON
TP5, TP6, TP7, TP8, TP9, TP10, TP11: TestPoint; TestPoint_Pad_D1.0mm; not fitted
U10: battery_charger; QFN-24-1EP_4x4mm_P0.5mm_EP2.7x2.6mm
U11: nRF52840_aQFN73; AQFN-73-1EP_7x7mm_P0.5mm_NRF52840-custom
U12: TS5A3159AYZPR; Texas_DSBGA-6_0.9x1.4mm_Layout2x3_P0.5mm
U13: BQ27427; Texas_DSBGA-9_1.62mmx1.58mm_Layout3x3_P0.5mm
U14: TPS22910A; BGA4N50P2X2_88X88X50N
U15, U16: A3144e; TSOT-23
U17: debug pins; not fitted
U18: pogopins; pogopin
U19: LSM6DS3; LGA-14_3x2.5mm_P0.5mm_LayoutBorder3x4y
U20, U21: TPS54202DDC; SOT-23-6
U26: 1615 RGB SMD LED
X3: 32.768 kHz; Crystal_SMD_2012-2Pin_2.0x1.2mm; Manufacturer Part SC20S-12.5PF20PPM; LCSC Part C97607
X4: 32MHZ; Crystal_SMD_2016-4Pin_2.0x1.6mm

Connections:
/pod/1.8V: C58.1, U13.B3 (VDD)
/pod/3V: C30.2, C31.2, C34.2, C46.2, C47.2, C48.2, C54.1, J9.2, JP4.1 (A), Q7.2 (S), R16.2, R17.2, R25.2, TP8.1, U11.A22 (VDD), U11.AD14 (VDD), U11.AD23 (VDD), U11.B1 (VDD), U11.W1 (VDD), U11.Y2 (VDDH), U12.B2 (V+), U17.1 (3V), U26.3 (+)
/pod/5V: F1.2, JP5.1 (A), Q10.2 (S), R35.1, TP7.1, U15.1 (5V), U16.1 (5V)
/pod/44E: R35.2, U11.AD10 (P0.15), U15.2 (D), U16.2 (D)
/pod/ARGBLED_5V: D6.2 (VDD), D7.2 (VDD), D8.2 (VDD), D9.2 (VDD), D10.2 (VDD), D11.2 (VDD), D12.2 (VDD), D13.2 (VDD), D14.2 (VDD), D15.2 (VDD), D16.2 (VDD), D17.2 (VDD), D18.2 (VDD), D19.2 (VDD), D20.2 (VDD), D21.2 (VDD), D22.2 (VDD), D23.2 (VDD), D24.2 (VDD), D25.2 (VDD), D26.2 (VDD), D27.2 (VDD), D28.2 (VDD), D29.2 (VDD), D30.2 (VDD), D31.2 (VDD), D32.2 (VDD), Q10.3 (D)
/pod/ARGB_LANE: R46.2, U11.AD12 (P0.17)
/pod/BATM: R26.2, U13.C3 (BAT)
/pod/BAT_P: C39.1, C41.2, C45.2, Q8.3 (D), SW6.2 (B), TP9.1, U10.12 (EN), U10.21 (VOUT), U10.22 (VOUT)
/pod/COM: C59.1, U12.A1, U14.A1 (VOUT), U18.1 (+); also elsewhere on the board
/pod/D+: U11.AD6 (D+); also elsewhere on the board
/pod/D-: U11.AD4 (D-); also elsewhere on the board
/pod/DCCH: U11.AB2 (DCCH)
/pod/EN_SK1824: U11.AC19 (P0.23), U14.B2 (ON)
/pod/IN_TS5A3159AYZPR: U11.A14 (P1.15), U12.A2
/pod/LED6: R15.2, U10.6 (LED)
/pod/MOS_5V: Q9.1 (G), R38.2, U11.B17 (P1.12)
/pod/MOS_EN: Q7.1 (G), R34.2, U11.U24 (P1.04)
/pod/MOS_LED_5V: Q10.1 (G), R45.2, U11.A16 (P1.13)
/pod/MOS_VDD: Q7.3 (D), R37.1, TP10.1, U19.5 (VDDIO), U19.8 (VDD)
/pod/P0.02: U11.A12 (AIN0/P0.02)
/pod/P0.07: U11.M2 (TRACECLK/P0.07)
/pod/P0.09: U11.L24 (NFC1/P0.09)
/pod/P0.10: U11.J24 (NFC2/P0.10)
/pod/P0.14: R20.1, U11.AC9 (P0.14)
/pod/P0.16: U11.AC11 (P0.16)
/pod/P0.24: U11.AD20 (P0.24)
/pod/P0.25: U11.AC21 (P0.25)
/pod/P0.28: U11.B11 (AIN4/P0.28)
/pod/P0.29: U11.A10 (AIN5/P0.29)
/pod/P0.30: U11.B9 (AIN6/P0.30)
/pod/P0.31: U11.A8 (AIN7/P0.31)
/pod/P1.03: U11.V23 (P1.03)
/pod/P1.05: U11.T23 (P1.05)
/pod/P1.06: U11.R24 (P1.06)
/pod/P1.07: U11.P23 (P1.07)
/pod/RX_TS5A3159AYZPR: R32.2, U11.N1 (P0.08), U12.C2
/pod/SAFE_5V: C50.1, F1.1, U14.A2 (VIN)
/pod/SCL: J9.3, R17.1, U11.T2 (TRACEDATA2/P0.11), U13.A3 (SCL), U19.13 (SCL)
/pod/SDA: J9.4, R25.1, U11.U1 (TRACEDATA1/P0.12), U13.A2 (SDA), U19.14 (SDA)
/pod/V: C60.2, D5.1 (K), Q8.2 (S), Q9.2 (S), R39.1, U20.3 (VIN)
/pod/VBUS: C42.2, D5.2 (A), L5.2, Q8.1 (G), R27.1, R28.2, R36.1, TP6.1, U11.AD2 (VBUS); also elsewhere on the board
/pod/int1: U11.AD8 (P0.13), U19.4 (INT1)
/pod/swc: U11.AA24 (SWDCLK), U17.4 (SWC); also elsewhere on the board
/pod/swd: U11.AC24 (SWDIO), U17.3 (SWD); also elsewhere on the board
/pod/vBATM: BT2.2 (-), BT3.1 (+), U13.C2 (SRX)
B-: R59.2, U11.B13 (AIN1/P0.03)
G-: R58.2, U11.B15 (P1.14)
GND: BT3.2 (-), C28.2, C29.2, C30.1, C31.1, C32.1, C33.1, C34.1, C36.1, C37.1, C38.1, C39.2, C40.1, C41.1, C42.1, C43.2, C44.2, C45.1, C46.1, C47.1, C48.1, C49.1, C50.2, C51.1, C52.1, C53.1, C54.2, C55.2, C56.1, C57.2, C58.2, C59.2, C60.1, C61.2, C66.1, C67.1, D2.1 (K), D6.3 (GND), D7.3 (GND), D8.3 (GND), D9.3 (GND), D10.3 (GND), D11.3 (GND), D12.3 (GND), D13.3 (GND), D14.3 (GND), D15.3 (GND), D16.3 (GND), D17.3 (GND), D18.3 (GND), D19.3 (GND), D20.3 (GND), D21.3 (GND), D22.3 (GND), D23.3 (GND), D24.3 (GND), D25.3 (GND), D26.3 (GND), D27.3 (GND), D28.3 (GND), D29.3 (GND), D30.3 (GND), D31.3 (GND), D32.3 (GND), J9.1, R18.1, R19.1, R21.1, R22.1, R23.1, R24.1, R28.1, R30.2, R31.1, R32.1, R34.1, R36.2, R38.1, R42.2, R44.2, R45.1, S4.2, TP5.1, U10.18 (PGND), U10.24 (VBAT_GND), U10.25 (GND), U11.B7 (VSS), U11.EP (VSS), U11.F23 (VSS_PA), U12.B1 (GND), U13.B2 (VSS), U13.C1 (VSS), U14.B1 (GND), U15.3 (GND), U16.3 (GND), U17.2 (GND), U18.2 (-), U19.6 (GND), U19.7 (GND), U20.1 (GND), U21.1 (GND), X4.2, X4.4; also elsewhere on the board
unnamed: AE2.1 (A), C57.1, R33.2
unnamed: BT2.1 (+), J5.2, SW6.1 (A)
unnamed: C35.2, L5.1, U10.15 (LX), U10.16 (LX), U10.17 (LX)
unnamed: C36.2, C37.2, U10.19 (VSYS), U10.20 (VSYS)
unnamed: C56.2, L8.2, R33.1
unnamed: D2.2 (A), R15.1
unnamed: D4.2 (A), U11.A20 (P1.10)
unnamed: D4.1 (K), R30.1
unnamed: D6.4 (DI), R46.1, TP11.1
unnamed: D6.1 (DO), D7.4 (DI)
unnamed: D7.1 (DO), D8.4 (DI)
unnamed: D8.1 (DO), D9.4 (DI)
unnamed: D9.1 (DO), D10.4 (DI)
unnamed: D10.1 (DO), D11.4 (DI)
unnamed: D11.1 (DO), D12.4 (DI)
unnamed: D12.1 (DO), D13.4 (DI)
unnamed: D13.1 (DO), D14.4 (DI)
unnamed: D14.1 (DO), D15.4 (DI)
unnamed: D15.1 (DO), D16.4 (DI)
unnamed: D16.1 (DO), D17.4 (DI)
unnamed: D17.1 (DO), D18.4 (DI)
unnamed: D18.1 (DO), D19.4 (DI)
unnamed: D19.1 (DO), D20.4 (DI)
unnamed: D20.1 (DO), D21.4 (DI)
unnamed: D21.1 (DO), D22.4 (DI)
unnamed: D22.1 (DO), D23.4 (DI)
unnamed: D23.1 (DO), D24.4 (DI)
unnamed: D24.1 (DO), D25.4 (DI)
unnamed: D25.1 (DO), D26.4 (DI)
unnamed: D26.1 (DO), D27.4 (DI)
unnamed: D27.1 (DO), D28.4 (DI)
unnamed: D28.1 (DO), D29.4 (DI)
unnamed: D29.1 (DO), D30.4 (DI)
unnamed: D30.1 (DO), D31.4 (DI)
unnamed: D31.1 (DO), D32.4 (DI)
unnamed: J5.1, SW6.3 (C)
unnamed: JP2.1 (A), JP3.2 (B), R16.1, S4.1
unnamed: JP2.2 (B), U11.P2 (P1.08)
unnamed: JP3.1 (A), U11.AC13 (P0.18/~RESET)
unnamed: C64.2, C66.2, JP4.2 (B), L9.2, R41.1
unnamed: C65.2, C67.2, JP5.2 (B), L10.2, R43.1
unnamed: L6.2, L7.1
unnamed: C61.1, Q9.3 (D), R40.1, U21.3 (VIN)
unnamed: R20.2, U10.5 (BAT_STAT)
unnamed: C35.1, U10.14 (BST)
unnamed: R24.2, U10.11 (ISET)
unnamed: R19.2, U10.4 (NTC)
unnamed: R21.2, U10.7 (TIME_SET)
unnamed: C38.2, R26.1, U10.23 (VBATM)
unnamed: C40.2, R27.2, U10.13 (VIN)
unnamed: R23.2, U10.9 (VIN_OVSET)
unnamed: R22.2, U10.8 (VIN_UVSET)
unnamed: R18.2, U10.3 (VSET)
unnamed: C49.2, L8.1, U11.H23 (ANT)
unnamed: L7.2, U11.B3 (DCC)
unnamed: C32.2, U11.C1 (DEC1)
unnamed: C55.1, U11.D23 (DEC3)
unnamed: C43.1, C44.1, L6.1, U11.B5 (DEC4), U11.E24 (DEC6)
unnamed: C53.2, U11.N24 (DEC5)
unnamed: C33.2, U11.AC5 (DECUSB)
unnamed: C52.2, U11.B24 (XC1), X4.1
unnamed: C51.2, U11.A23 (XC2), X4.3
unnamed: C28.1, U11.D2 (XL1/P0.00), X3.1
unnamed: C29.1, U11.F2 (XL2/P0.01), X3.2
unnamed: R31.2, U13.B1 (BIN)
unnamed: R37.2, U19.12 (CS)
unnamed: C62.1, U20.6 (BOOT)
unnamed: R39.2, U20.5 (EN)
unnamed: C64.1, R41.2, R42.1, U20.4 (FB)
unnamed: C62.2, L9.1, U20.2 (SW)
unnamed: C63.1, U21.6 (BOOT)
unnamed: R40.2, U21.5 (EN)
unnamed: C65.1, R43.2, R44.1, U21.4 (FB)
unnamed: C63.2, L10.1, U21.2 (SW)
unnamed: R59.1, U26.4 (B-)
unnamed: R58.1, U26.2 (G-)
unnamed: R7.2, U26.1 (R-)
R-: R7.1, U11.B19 (P1.11)

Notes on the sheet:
a lot of argbleds
2s battery charger circuit
usbc
RX OF NRF
0x55
ANALOG SWITCH
POGOPIN+
polyfuse for output5v short circuit protection
OUTPUT 5V
power path
debug pins
battery and vbus to 3v and 5v converters
POWER CONTROL MOSFET
gyroscope
FUEL GAUGE
batteries
because that there is an orientation to the hall effect sensor i have two footprints that are facing both ways just incase that one of the orientations are not correct
voltage test pads
pogopins
nrf
hall effect sensor
LOAD SWITCH
GPIO OF NRF

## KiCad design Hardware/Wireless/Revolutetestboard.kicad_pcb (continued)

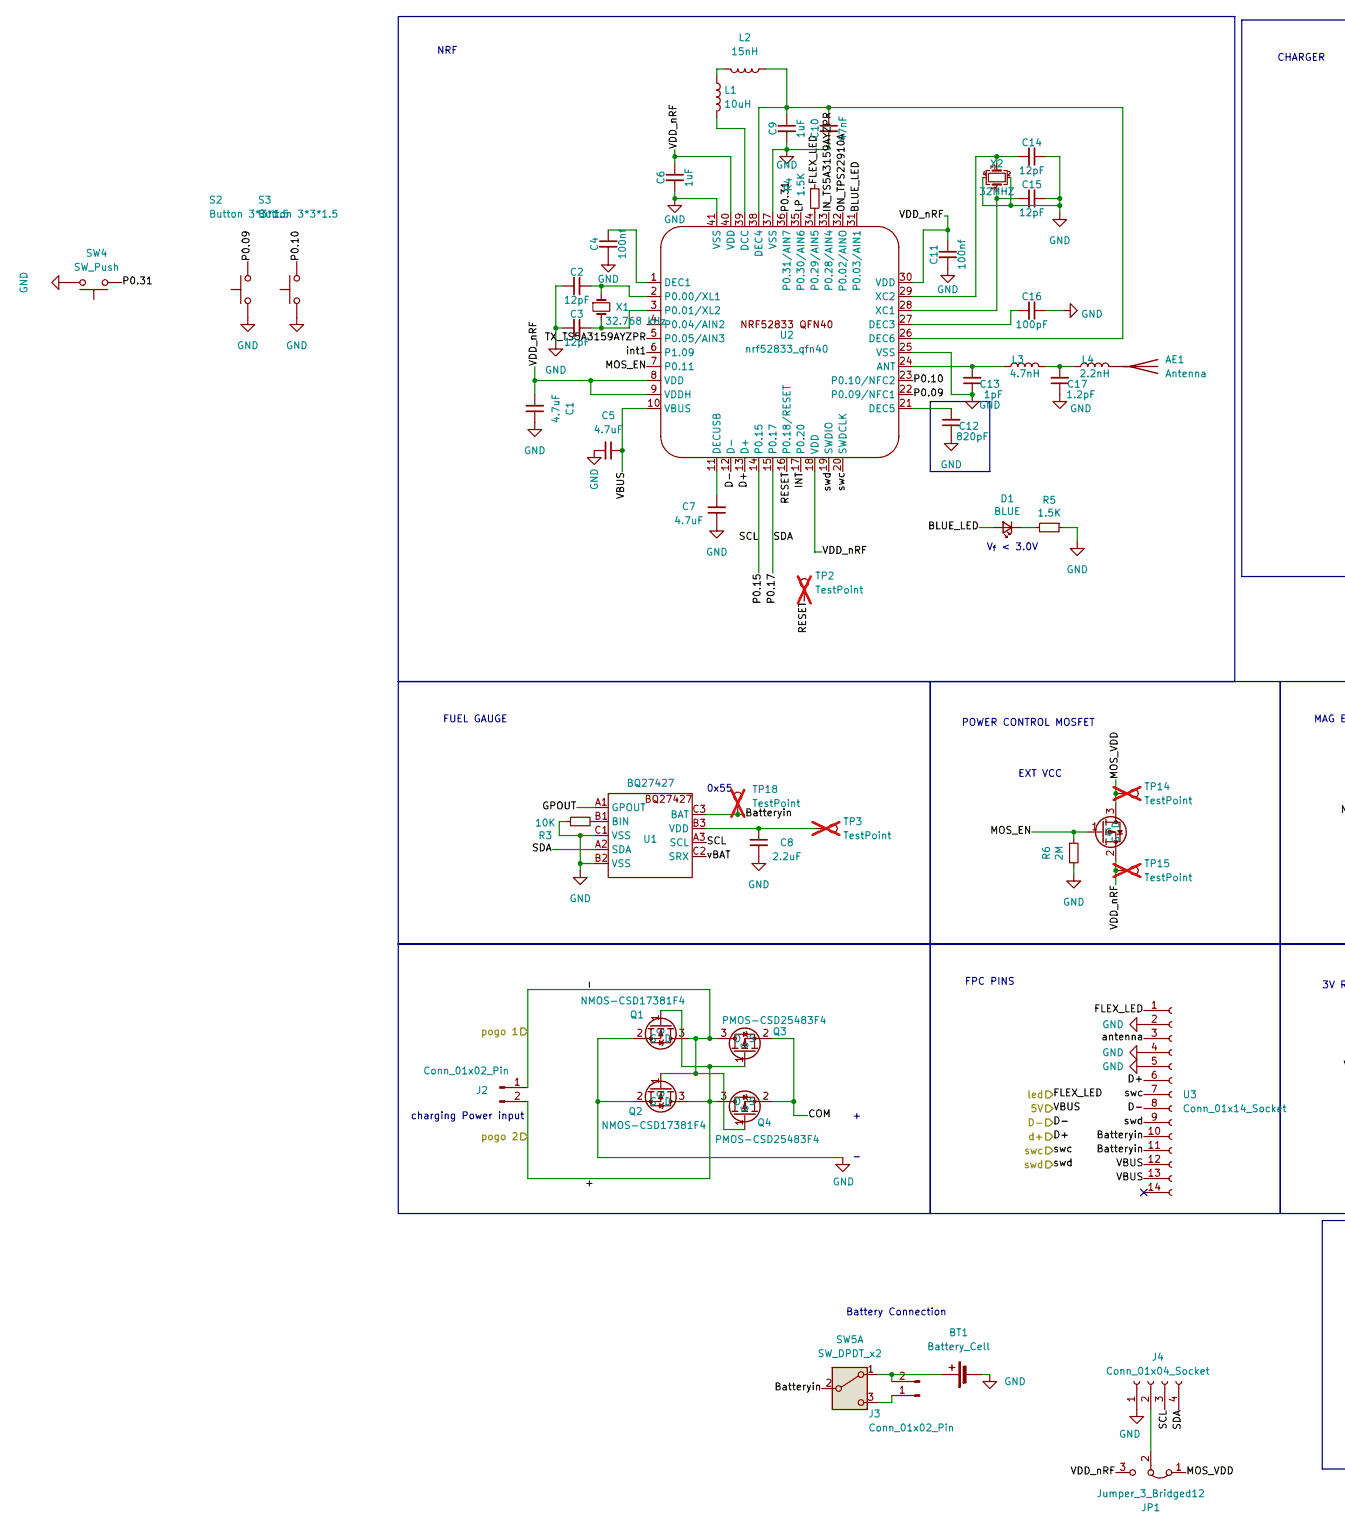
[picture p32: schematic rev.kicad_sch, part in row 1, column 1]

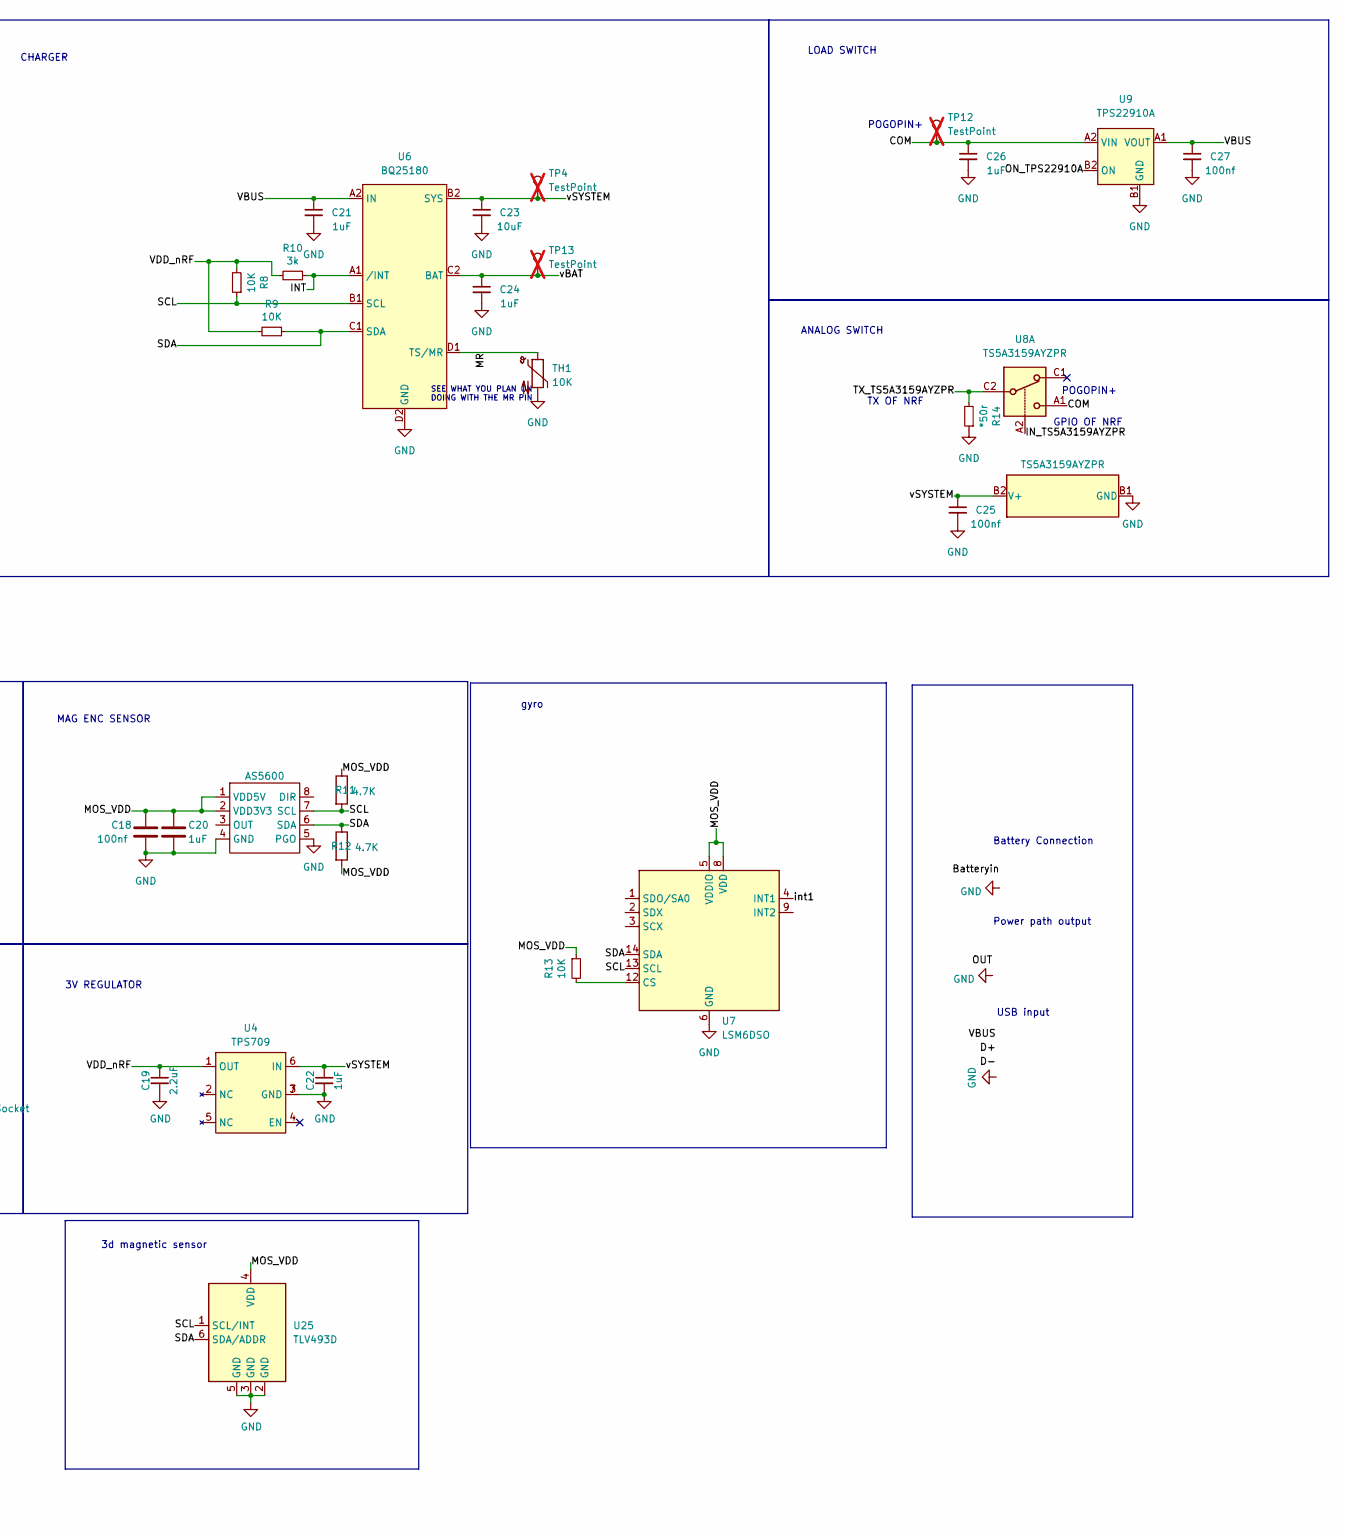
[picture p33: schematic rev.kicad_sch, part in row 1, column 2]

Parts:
AE1: Antenna; 2.4GHz-meander-antenna
BT1: Battery_Cell; BatteryHolder_Keystone_1057_1x2032
C1, C5, C7: 4.7uF; 0402
C2, C3, C14, C15: 12pF; 0402
C4, C11, C18, C25, C27: 100nf; 0402
C6, C9, C20, C21, C22, C24, C26: 1uF; 0402
C8, C19: 2.2uF; 0402
C10: 47nF; 0402
C12: 820pF; 0402
C13: 1pF; 0402
C16: 100pF; 0402
C17: 1.2pF; 0402
C23: 10uF; 0402
D1: BLUE; LED_0402_1005Metric
J2, J3: Conn_01x02_Pin; PinHeader_1x02_P2.54mm_Vertical
J4: Conn_01x04_Socket; PinSocket_1x04_P2.54mm_Vertical
JP1: Jumper_3_Bridged12; SolderJumper-3_P1.3mm_Bridged12_RoundedPad1.0x1.5mm
L1: 10uH; 0402
L2: 15nH; 0402
L3: 4.7nH; 0402
L4: 2.2nH; 0402
Q1, Q2: NMOS-CSD17381F4; Mosfet0402
Q3, Q4, Q5: PMOS-CSD25483F4; Mosfet0402
R3, R13: 10K; 0402
R4, R5: 1.5K; 0402
R6: 2M; 0402
R8, R9: 10K; R_0402_1005Metric
R10: 3k; R_0402_1005Metric
R11, R12: 4.7K; 0402
R14: *50r; R_0402_1005Metric
S2, S3: Button 3*3*1.5; button 3x3
SW4: SW_Push; 16mmCompButton
SW5: SW_DPDT_x2; MST-12C05 SLIDEBUTTON
TH1: 10K; R_0402_1005Metric
TP2, TP3, TP4, TP12, TP13, TP14, TP15, TP18: TestPoint; TestPoint_Pad_D1.0mm; not fitted
U1: BQ27427; Texas_DSBGA-9_1.62mmx1.58mm_Layout3x3_P0.5mm
U2: nrf52833_qfn40; nrf52833
U3: Conn_01x14_Socket; FPC
U4: TPS709; DRV 6PIN
U5: AS5600; SOIC-8-1EP_3.9x4.9mm_P1.27mm_EP2.514x3.2mm
U6: BQ25180; Texas_DSBGA-8_0.705x1.468mm_Layout2x4_P0.4mm
U7: LSM6DSO; LGA-14_3x2.5mm_P0.5mm_LayoutBorder3x4y
U8: TS5A3159AYZPR; Texas_DSBGA-6_0.9x1.4mm_Layout2x3_P0.5mm
U9: TPS22910A; BGA4N50P2X2_88X88X50N
U25: TLV493D; SOT-23-6-Small
X1: 32.768 kHz; Crystal_SMD_2012-2Pin_2.0x1.2mm
X2: 32MHZ; Crystal_SMD_2016-4Pin_2.0x1.6mm

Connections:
/rev/+: J2.2, Q1.1 (G), Q2.3 (D), Q3.1 (G), Q4.3 (D); also elsewhere on the board
/rev/-: J2.1, Q1.3 (D), Q2.1 (G), Q3.3 (D), Q4.1 (G); also elsewhere on the board
/rev/BLUE_LED: D1.2 (A), U2.31 (P0.03/AIN1)
/rev/Batteryin: SW5.2 (B), TP18.1, U1.C3 (BAT), U3.10, U3.11
/rev/COM: C26.1, Q3.2 (S), Q4.2 (S), TP12.1, U8.A1, U9.A2 (VIN)
/rev/D+: U2.13 (D+), U3.6; also elsewhere on the board
/rev/D-: U2.12 (D-), U3.8; also elsewhere on the board
/rev/FLEX_LED: R4.1, U3.1; also elsewhere on the board
/rev/GPOUT: U1.A1 (GPOUT)
/rev/INT: R10.1, U2.17 (P0.20), U6.A1 (/INT)
/rev/IN_TS5A3159AYZPR: U2.33 (P0.28/AIN4), U8.A2
/rev/LP: U2.35 (P0.30/AIN6)
/rev/MOS_EN: Q5.1 (G), R6.1, U2.7 (P0.11)
/rev/MOS_VDD: C18.1, C20.1, JP1.1 (A), Q5.3 (D), R11.1, R12.2, R13.1, TP14.1, U5.1 (VDD5V), U5.2 (VDD3V3), U7.5 (VDDIO), U7.8 (VDD), U25.4 (VDD)
/rev/MR: TH1.1, U6.D1 (TS/MR)
/rev/ON_TPS22910A: U2.32 (P0.02/AINO), U9.B2 (ON)
/rev/P0.09: S2.2, U2.22 (P0.09/NFC1)
/rev/P0.10: S3.2, U2.23 (P0.10/NFC2)
/rev/P0.15: J4.3, R8.1, R11.2, U1.A3 (SCL), U2.14 (P0.15), U5.7 (SCL), U6.B1 (SCL), U7.13 (SCL), U25.1 (SCL/INT)
/rev/P0.17: J4.4, R9.1, R12.1, U1.A2 (SDA), U2.15 (P0.17), U5.6 (SDA), U6.C1 (SDA), U7.14 (SDA), U25.6 (SDA/ADDR)
/rev/P0.31: SW4.1, U2.36 (P0.31/AIN7)
/rev/RESET: TP2.1, U2.16 (P0.18/RESET)
/rev/TX_TS5A3159AYZPR: R14.2, U2.5 (P0.05/AIN3), U8.C2
/rev/VBUS: C5.1, C21.1, C27.1, U2.10 (VBUS), U3.12, U3.13, U6.A2 (IN), U9.A1 (VOUT); also elsewhere on the board
/rev/VDD_nRF: C1.2, C6.1, C11.1, C19.1, JP1.3 (B), Q5.2 (S), R8.2, R9.2, R10.2, TP15.1, U2.8 (VDD), U2.9 (VDDH), U2.18 (VDD), U2.30 (VDD), U2.40 (VDD), U4.1 (OUT)
/rev/antenna: U3.3
/rev/int1: U2.6 (P1.09), U7.4 (INT1)
/rev/swc: U2.20 (SWDCLK), U3.7; also elsewhere on the board
/rev/swd: U2.19 (SWDIO), U3.9; also elsewhere on the board
/rev/vBAT: C24.1, TP13.1, U1.C2 (SRX), U6.C2 (BAT)
/rev/vSYSTEM: C22.1, C23.1, C25.1, TP4.1, U4.6 (IN), U6.B2 (SYS), U8.B2 (V+)
GND: BT1.2 (-), C1.1, C2.2, C3.2, C4.2, C5.2, C6.2, C7.1, C8.2, C9.2, C10.2, C11.2, C12.1, C13.1, C14.1, C15.1, C16.1, C17.1, C18.2, C19.2, C20.2, C21.2, C22.2, C23.2, C24.2, C25.2, C26.2, C27.2, J4.1, Q1.2 (S), Q2.2 (S), R3.1, R5.1, R6.2, R14.1, S2.1, S3.1, SW4.2, TH1.2, U1.B2 (VSS), U1.C1 (VSS), U2.25 (VSS), U2.37 (VSS), U2.41 (VSS), U3.2, U3.4, U3.5, U4.3 (GND), U4.7 (GND), U5.4 (GND), U5.5 (PGO), U6.D2 (GND), U7.6 (GND), U7.7 (GND), U8.B1 (GND), U9.B1 (GND), U25.2 (GND), U25.3 (GND), U25.5 (GND), X2.2, X2.4; also elsewhere on the board
unnamed: AE1.1 (A), L4.2
unnamed: BT1.1 (+), J3.2, SW5.1 (A)
unnamed: C17.2, L3.2, L4.1
unnamed: D1.1 (K), R5.2
unnamed: J3.1, SW5.3 (C)
unnamed: J4.2, JP1.2 (C)
unnamed: L1.1, L2.2
unnamed: R3.2, U1.B1 (BIN)
unnamed: C8.1, TP3.1, U1.B3 (VDD)
unnamed: C13.2, L3.1, U2.24 (ANT)
unnamed: L1.2, U2.39 (DCC)
unnamed: C4.1, U2.1 (DEC1)
unnamed: C16.2, U2.27 (DEC3)
unnamed: C9.1, C10.1, L2.1, U2.26 (DEC6), U2.38 (DEC4)
unnamed: C12.2, U2.21 (DEC5)
unnamed: C7.2, U2.11 (DECUSB)
unnamed: C2.1, U2.2 (P0.00/XL1), X1.1
unnamed: C3.1, U2.3 (P0.01/XL2), X1.2
unnamed: R4.2, U2.34 (P0.29/AIN5)
unnamed: C15.2, U2.28 (XC1), X2.1
unnamed: C14.2, U2.29 (XC2), X2.3
unnamed: R13.2, U7.12 (CS)

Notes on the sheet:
FPC PINS
LOAD SWITCH
ANALOG SWITCH
USB input
NRF
3V REGULATOR
MAG ENC SENSOR
V_{f} < 3.0V
charging Power input
POWER CONTROL MOSFET
3d magnetic sensor
EXT VCC
Battery Connection
CHARGER
POGOPIN+
TX OF NRF
Power path output
FUEL GAUGE
gyro
GPIO OF NRF
SEE WHAT YOU PLAN ON DOING WITH THE MR PIN
0x55

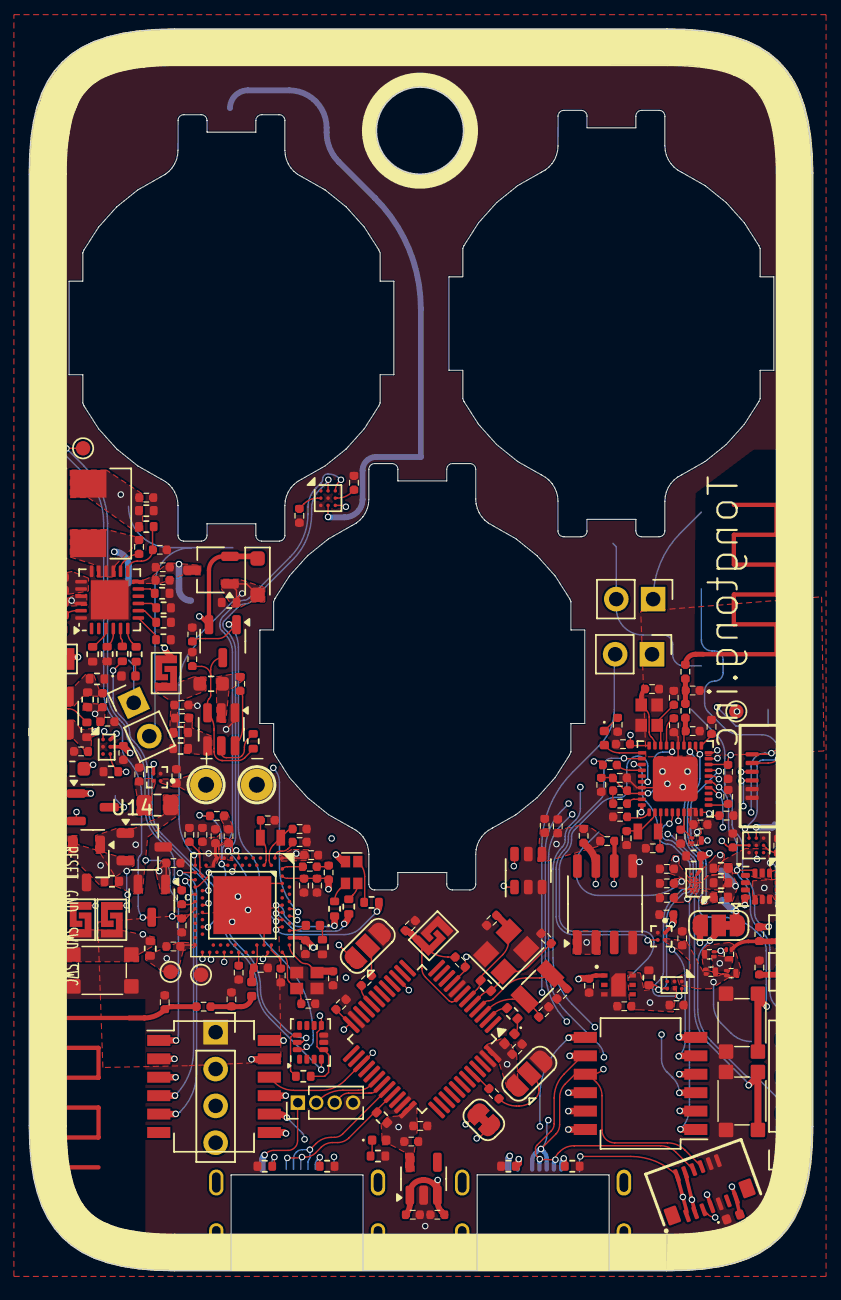
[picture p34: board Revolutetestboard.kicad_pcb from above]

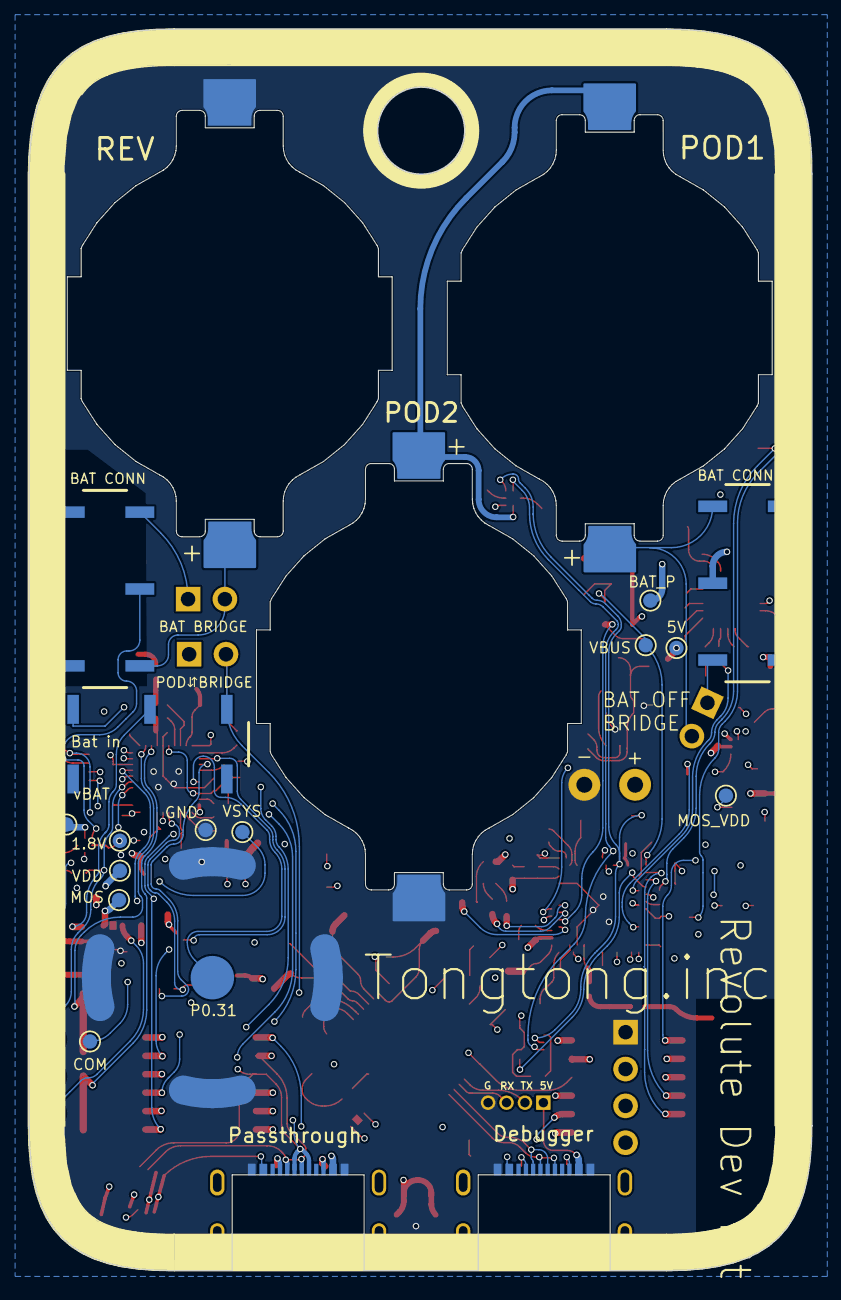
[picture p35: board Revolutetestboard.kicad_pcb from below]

Board: 4 copper layers, 54.0 x 85.6 mm, 271 parts (21 on the bottom side), 191 nets.

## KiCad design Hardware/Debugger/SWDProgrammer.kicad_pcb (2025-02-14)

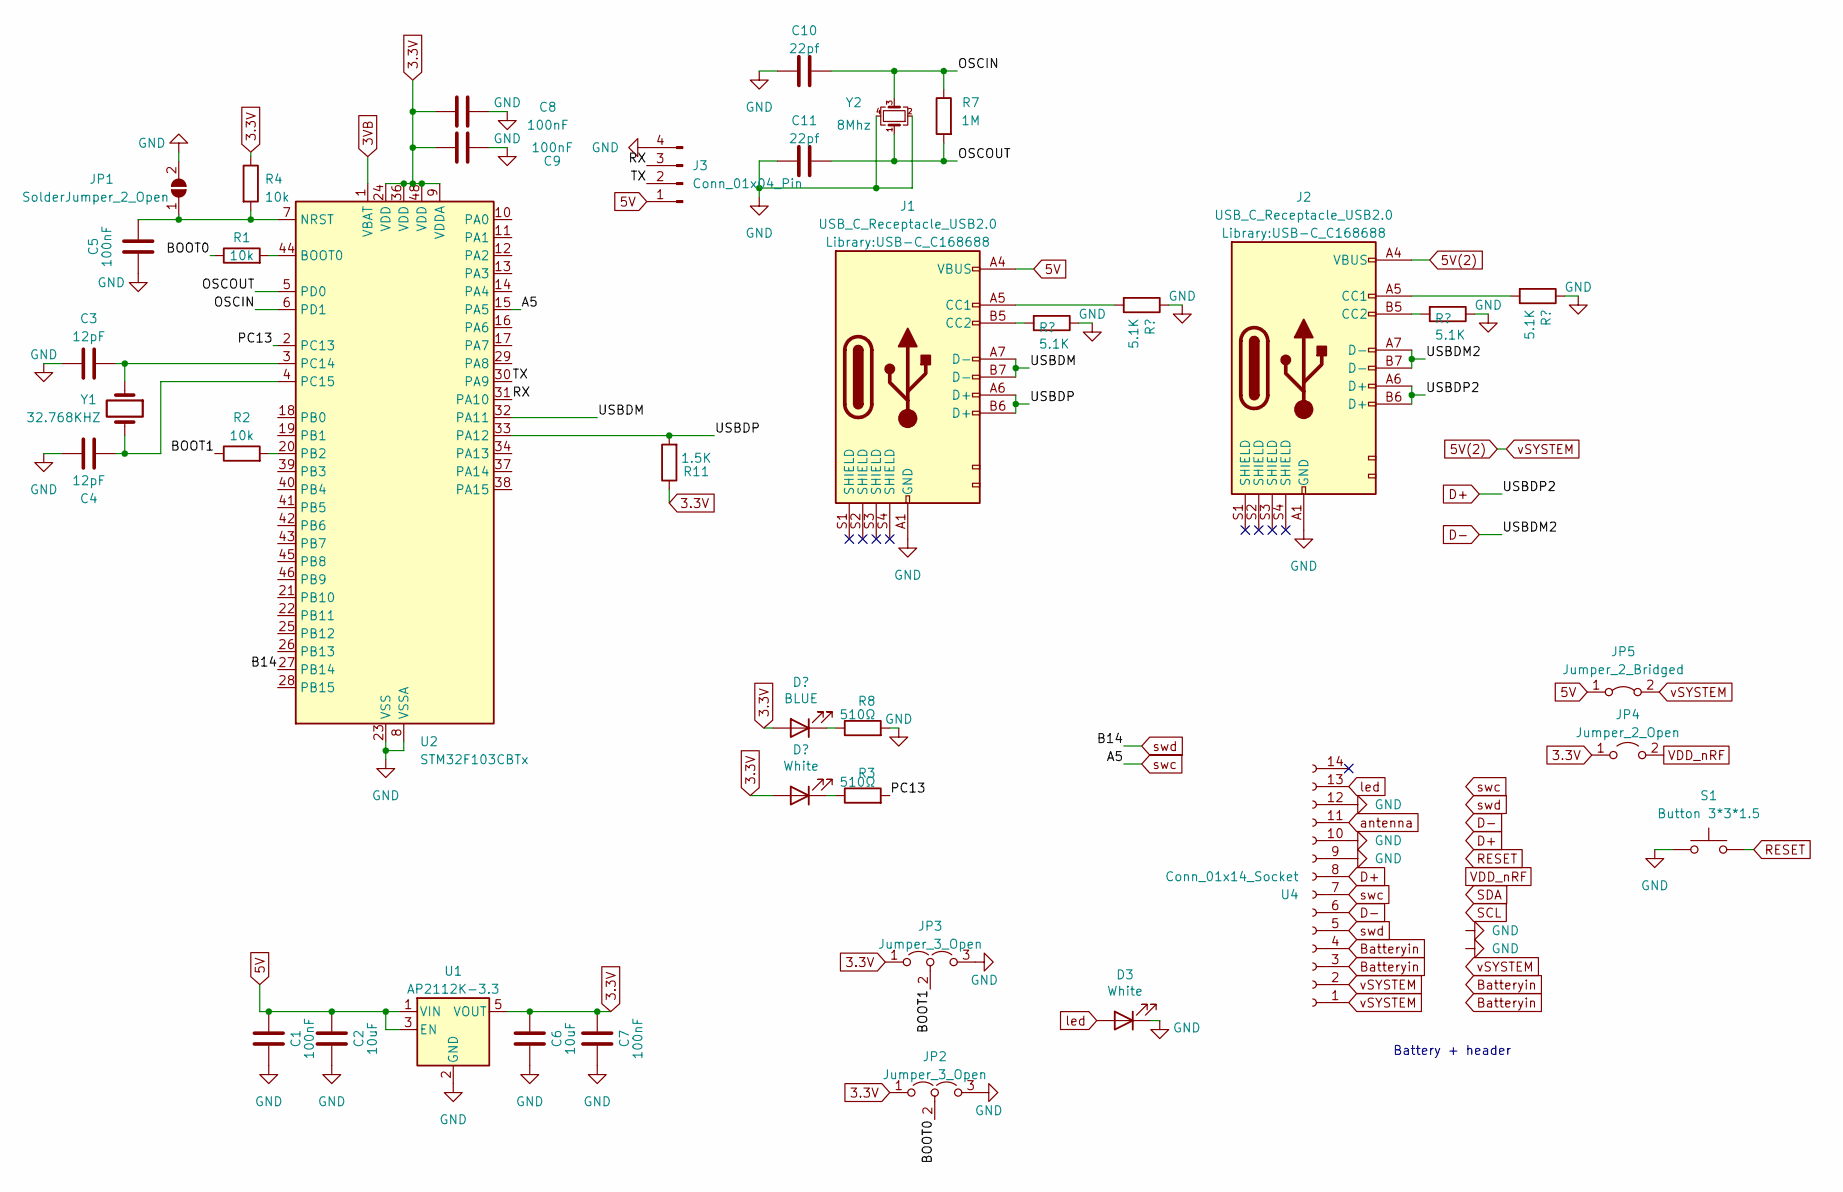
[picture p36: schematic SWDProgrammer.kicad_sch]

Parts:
C1, C5, C7, C8, C9: 100nF; C_0402_1005Metric
C2, C6: 10uF; C_0402_1005Metric
C3, C4: 12pF; C_0402_1005Metric
C10, C11: 22pf; C_0402_1005Metric
D1, D3: White; LED_0402_1005Metric
D2: BLUE; LED_0402_1005Metric
J1, J2: USB_C_Receptacle_USB2.0; USB-C_C168688
J3: Conn_01x04_Pin; PinHeader_1x04_P1.27mm_Vertical
JP1: SolderJumper_2_Open; SolderJumper-2_P1.3mm_Open_RoundedPad1.0x1.5mm
JP2, JP3: Jumper_3_Open; SolderJumper-3_P1.3mm_Open_RoundedPad1.0x1.5mm
JP4: Jumper_2_Open; SolderJumper-2_P1.3mm_Open_RoundedPad1.0x1.5mm
JP5: Jumper_2_Bridged; SolderJumper-2_P1.3mm_Bridged_RoundedPad1.0x1.5mm
R1, R2, R4: 10k; R_0402_1005Metric
R3, R8: 510Ω; R_0402_1005Metric
R7: 1M; R_0402_1005Metric
R9, R10, R12, R13: 5.1K; R_0402_1005Metric
R11: 1.5K; R_0402_1005Metric
S1: Button 3*3*1.5; button 3x3
U1: AP2112K-3.3; SOT-23-5
U2: STM32F103CBTx; LQFP-48_7x7mm_P0.5mm
U4: Conn_01x14_Socket; FPC
Y1: 32.768KHZ; Crystal_SMD_3215-2Pin_3.2x1.5mm
Y2: 8Mhz; Crystal_SMD_3225-4Pin_3.2x2.5mm

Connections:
3.3V: C6.2, C7.2, C8.2, C9.2, D1.2 (A), D2.2 (A), JP2.1 (A), JP3.1 (A), JP4.1 (A), R4.1, R11.1, U1.5 (VOUT), U2.9 (VDDA), U2.24 (VDD), U2.36 (VDD), U2.48 (VDD)
3VB: U2.1 (VBAT)
5V: C1.2, C2.2, J1.A4 (VBUS), J3.1, JP5.1 (A), U1.1 (VIN), U1.3 (EN)
5V(2): J2.A4 (VBUS), JP5.2 (B), U4.1, U4.2
/BOOT0: JP2.2 (C), R1.1
/BOOT1: JP3.2 (C), R2.1
/OSCIN: C10.2, R7.1, U2.6 (PD1), Y2.3
/OSCOUT: C11.2, R7.2, U2.5 (PD0), Y2.1
/PC13: R3.2, U2.2 (PC13)
/RX: J3.3, U2.31 (PA10)
/TX: J3.2, U2.30 (PA9)
/USBDM: J1.A7 (D-), J1.B7 (D-), U2.32 (PA11)
/USBDP: J1.A6 (D+), J1.B6 (D+), R11.2, U2.33 (PA12)
Batteryin: U4.3, U4.4
D+: J2.A6 (D+), J2.B6 (D+), U4.8
D-: J2.A7 (D-), J2.B7 (D-), U4.6
GND: C1.1, C2.1, C3.1, C4.2, C5.1, C6.1, C7.1, C8.1, C9.1, C10.1, C11.1, D3.1 (K), J1.A1 (GND), J2.A1 (GND), J3.4, JP1.2 (B), JP2.3 (B), JP3.3 (B), R8.2, R9.1, R10.1, R12.1, R13.1, S1.1, U1.2 (GND), U2.8 (VSSA), U2.23 (VSS), U2.35 (VSS), U2.47 (VSS), U4.9, U4.10, U4.12, Y2.2, Y2.4
unnamed: D1.1 (K), R3.1
unnamed: D2.1 (K), R8.1
unnamed: J1.A5 (CC1), R10.2
unnamed: J1.B5 (CC2), R9.2
unnamed: J2.A5 (CC1), R13.2
unnamed: J2.B5 (CC2), R12.2
unnamed: C5.2, JP1.1 (A), R4.2, U2.7 (NRST)
unnamed: R1.2, U2.44 (BOOT0)
unnamed: R2.2, U2.20 (PB2)
unnamed: C3.2, U2.3 (PC14), Y1.1
unnamed: C4.1, U2.4 (PC15), Y1.2
antenna: U4.11
led: D3.2 (A), U4.13
swc: U2.15 (PA5), U4.7
swd: U2.27 (PB14), U4.5

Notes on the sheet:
Battery + header

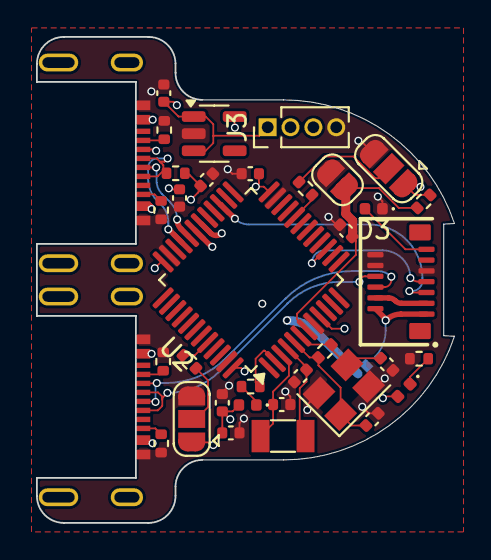
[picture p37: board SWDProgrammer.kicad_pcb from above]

Board: 4 copper layers, 23.2 x 27.0 mm, 37 parts (1 on the bottom side), 30 nets.

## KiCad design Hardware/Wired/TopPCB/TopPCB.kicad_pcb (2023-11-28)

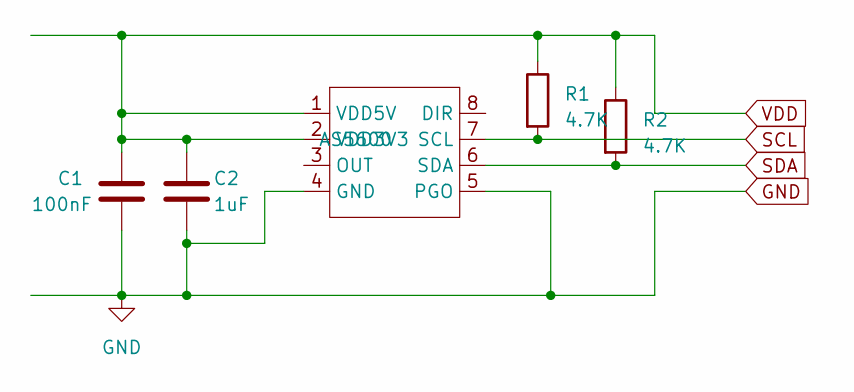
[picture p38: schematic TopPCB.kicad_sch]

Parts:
C1: 100nF; C_0402_1005Metric
C2: 1uF; C_0402_1005Metric
R1, R2: 4.7K; R_0402_1005Metric
U1: AS5600; SOIC-8-1EP_3.9x4.9mm_P1.27mm_EP2.514x3.2mm

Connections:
GND: C1.2, C2.2, U1.4 (GND), U1.5 (PGO)
SCL: R1.2, U1.7 (SCL)
SDA: R2.2, U1.6 (SDA)
VDD: C1.1, C2.1, R1.1, R2.1, U1.1 (VDD5V), U1.2 (VDD3V3)

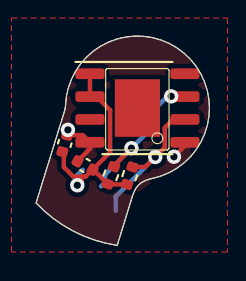
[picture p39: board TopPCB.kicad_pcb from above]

Board: 4 copper layers, 9.6 x 11.6 mm, 5 parts (0 on the bottom side), 4 nets.

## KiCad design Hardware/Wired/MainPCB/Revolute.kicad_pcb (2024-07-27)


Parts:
C1, C5, C7: 4.7uF; Capacitor-0201
C2, C3, C15, C16: 12pF; Capacitor-0201
C4, C11: 100nF; Capacitor-0201
C6, C8, C9, C13: 1uF; Capacitor-0201
C10: 47nF; Capacitor-0201
C12: 820pF; Capacitor-0201
C17: 100pF; Capacitor-0201
D1: BLUE; LED_0402_1005Metric
J1: USB_A; USB_Intergrated
L1: 10uH; L_0402_1005Metric
L2: 15nH; L_0402_1005Metric
R1: 1.5k; Resistor_0402_1005M-nosilk; Manufacturer Part RC0402FR-071K5L; LCSC Part C114759
U1: nrf52833_qfn40; QFN-40-1EP_5x5mm_P0.4mm_EP3.6x3.6mm
U2: MIC5504; TDFN-4
X1: 32.768 kHz; Crystal_SMD_2012-2Pin_2.0x1.2mm
X2: 32MHZ; Crystal_SMD_2016-4Pin_2.0x1.6mm

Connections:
ASOUT: U1.7 (P0.11)
BLUE_LED: D1.2 (A), U1.31 (P0.03/AIN1)
D+: J1.3 (D+), U1.13 (D+)
D-: J1.2 (D-), U1.12 (D-)
DIR: U1.6 (P1.09)
GND: C1.1, C2.2, C3.2, C4.2, C5.2, C6.2, C7.1, C8.2, C9.2, C10.2, C11.2, C12.1, C13.2, C15.1, C16.1, C17.1, J1.4 (GND), R1.1, U1.25 (VSS), U1.37 (VSS), U1.41 (VSS), U2.2 (GND), U2.5 (GND), X2.2, X2.4
unnamed: D1.1 (K), R1.2
unnamed: L1.1, L2.2
unnamed: L1.2, U1.39 (DCC)
unnamed: C4.1, U1.1 (DEC1)
unnamed: C17.2, U1.27 (DEC3)
unnamed: C9.1, C10.1, L2.1, U1.26 (DEC6), U1.38 (DEC4)
unnamed: C12.2, U1.21 (DEC5)
unnamed: C7.2, U1.11 (DECUSB)
unnamed: C2.1, U1.2 (P0.00/XL1), X1.1
unnamed: C3.1, U1.3 (P0.01/XL2), X1.2
unnamed: C16.2, U1.28 (XC1), X2.1
unnamed: C15.2, U1.29 (XC2), X2.3
P0.15: U1.14 (P0.15)
P0.17: U1.15 (P0.17)
P0.20: U1.17 (P0.20)
P0.28: U1.33 (P0.28/AIN4)
P0.29: U1.34 (P0.29/AIN5)
P0.30: U1.35 (P0.30/AIN6)
P0.31: U1.36 (P0.31/AIN7)
RESET: U1.16 (P0.18/RESET)
VBUS: C5.1, C8.1, J1.1 (VBUS), U1.10 (VBUS), U2.3 (EN), U2.4 (VIN)
VDD_nRF: C1.2, C6.1, C11.1, C13.1, U1.8 (VDD), U1.9 (VDDH), U1.18 (VDD), U1.30 (VDD), U1.40 (VDD), U2.1 (VOUT)
swc: U1.20 (SWDCLK)
swd: U1.19 (SWDIO)

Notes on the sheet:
V_{f} < 3.0V


Board: 4 copper layers, 18.0 x 11.2 mm, 25 parts (0 on the bottom side), 18 nets.

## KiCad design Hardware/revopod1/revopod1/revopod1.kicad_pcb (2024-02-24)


Board: 4 copper layers, 60.0 x 37.0 mm, 53 parts (0 on the bottom side), 45 nets.

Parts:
B1: 300mah; battery
C1, C3: 1uF; C_0402_1005Metric_Pad0.74x0.62mm_HandSolder
C2: 0.47uF; C_0402_1005Metric_Pad0.74x0.62mm_HandSolder
C4: 4.7uF; C_0402_1005Metric_Pad0.74x0.62mm_HandSolder
C5: 0.1u; C_0402_1005Metric_Pad0.74x0.62mm_HandSolder
C6, C7, C8: 22uF; C_0402_1005Metric_Pad0.74x0.62mm_HandSolder
D1: LEDR; LED_0402_1005Metric_Pad0.77x0.64mm_HandSolder
D2: LEDB; LED_0402_1005Metric_Pad0.77x0.64mm_HandSolder
D3: SS34; D_SMA_Handsoldering
D4, D5, D6, D7, D8, D9, D10, D11, D12, D13: Led-ARGB
L1: 22uH; L_7.3x7.3_H4.5
Q1: 8205A
Q2: BSS84; SOT-23
R3: 0.01; R_0402_1005Metric_Pad0.72x0.64mm_HandSolder
R4, R5: 4.7k; R_0402_1005Metric_Pad0.72x0.64mm_HandSolder
R6, R15, R19: 10k; R_0402_1005Metric_Pad0.72x0.64mm_HandSolder
R7, R8: 1.1k; R_0402_1005Metric_Pad0.72x0.64mm_HandSolder
R9, R10, R14: 1k; R_0402_1005Metric_Pad0.72x0.64mm_HandSolder
R11: 2k; R_0402_1005Metric_Pad0.72x0.64mm_HandSolder
R12: 100; R_0402_1005Metric_Pad0.72x0.64mm_HandSolder
R13: 7.5k; R_0402_1005Metric_Pad0.72x0.64mm_HandSolder
R17, R18: 22pF; R_0402_1005Metric_Pad0.72x0.64mm_HandSolder
SW1: SW_Push; button 3x3
U1: BQ24075RGT; VQFN-16-1EP_3x3mm_P0.5mm_EP1.6x1.6mm
U2: BQ27441-G1; Texas_S-PDSO-N12
U3: MT3608
U4: ATmega328-A; TQFP-32_7x7mm_P0.8mm
U5: pogopins; pogopin
U6: FS312F-G
U7: arduinnno pinnnns; arduino pins
U8: A3144; a3144
U9: usbcpads
U11: APE8865NR-19-HF-3; SOT-23
Y1: 16mhz; Crystal_SMD_5032-2Pin_5.0x3.2mm

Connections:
3V: C6.1, L1.2, R4.1, R5.1, R6.1, U3.4 (EN), U3.5 (IN), U11.2 (VO)
5V: C7.1, D3.1 (K), D4.2 (VDD), D5.2 (VDD), D6.2 (VDD), D7.2 (VDD), D8.2 (VDD), D9.2 (VDD), D10.2 (VDD), D11.2 (VDD), D12.2 (VDD), D13.2 (VDD), Q2.3 (D), R13.1, R19.1, U4.4 (VCC), U4.6 (VCC), U7.2 (VCC), U8.1 (5V)
B2: D4.4 (DI), U4.14 (PB2)
BAT+: B1.1 (+), C1.1, R3.1, R12.2, U2.6 (BAT), U2.8 (SRP)
BAT-: B1.2 (-), C1.2, C2.2, C3.2, C4.2, C6.2, C7.2, C8.1, D4.3 (GND), D5.3 (GND), D6.3 (GND), D7.3 (GND), D8.3 (GND), D9.3 (GND), D10.3 (GND), D11.3 (GND), D12.3 (GND), D13.3 (GND), Q1.1 (S1), Q1.3 (S2), Q2.1 (G), R7.1, R8.1, R11.2, R14.2, R17.1, R18.1, SW1.2, U1.5 (EN2), U1.6 (EN1), U1.8 (VSS), U1.14 (TMR), U1.17 (VSS), U2.3 (V_{SS}), U2.13 (PAD), U3.2 (GND), U4.3 (GND), U4.5 (GND), U4.21 (GND), U5.2 (-), U7.5 (RST), U7.6 (GND), U8.2 (GND), U9.2 (GND), U11.3 (GND)
FB: R13.2, R14.1, U3.3 (FB)
GPOUT: R6.2, U2.12 (GPOUT), U4.1 (PD3)
unnamed: D1.1 (K), R9.2
unnamed: D2.1 (K), R10.2
unnamed: D3.2 (A), L1.1, U3.1 (SW)
unnamed: D4.1 (DO), D5.4 (DI)
unnamed: D5.1 (DO), D6.4 (DI)
unnamed: D6.1 (DO), D7.4 (DI)
unnamed: D7.1 (DO), D8.4 (DI)
unnamed: D8.1 (DO), D9.4 (DI)
unnamed: D9.1 (DO), D10.4 (DI)
unnamed: D10.1 (DO), D11.4 (DI)
unnamed: D11.1 (DO), D12.4 (DI)
unnamed: D12.1 (DO), D13.4 (DI)
unnamed: Q2.2 (S), U5.1 (+)
unnamed: R7.2, U1.12 (ILIM)
unnamed: R8.2, U1.16 (ISET)
unnamed: R10.1, U1.9 (~CHG)
unnamed: C2.1, U2.5 (V_{DD})
unnamed: R15.1, SW1.1, U4.29 (~RESET/PC6)
unnamed: R11.1, U6.2 (CS)
unnamed: C5.1, U6.6 (GND)
unnamed: C5.2, R12.1, U6.5 (VCC)
OC: Q1.4 (G2), U6.3 (OC)
OD: Q1.6 (G1), U6.1 (OD)
OUT: C4.1, D1.2 (A), D2.2 (A), R15.2, U1.10 (OUT), U1.11 (OUT), U11.1 (VI)
PB3: U4.15 (PB3), U7.4 (MOSI)
PB4: U4.16 (PB4), U7.1 (MISO)
PB5: U4.17 (PB5), U7.3 (SCK)
PB6: R18.2, U4.7 (XTAL1/PB6), Y1.1
PB7: R17.2, U4.8 (XTAL2/PB7), Y1.2
PD6: C8.2, R19.2, U4.10 (PD6), U8.3 (D)
PGOOD: R9.1, U1.7 (~PGOOD)
RX: U4.30 (PD0), U7.7 (RX)
SCL: R5.2, U2.2 (SCL), U4.28 (PC5)
SDA: R4.2, U2.1 (SDA), U4.27 (PC4)
TS: U1.1 (TS), U2.10 (BIN)
TX: U4.31 (PD1), U7.8 (TX)
VBUS: C3.1, U1.13 (IN), U9.1 (VBUS)
V_BATT: R3.2, U1.2 (BAT), U1.3 (BAT), U2.7 (SRN)

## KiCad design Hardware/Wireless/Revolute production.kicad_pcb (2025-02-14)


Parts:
C1, C5, C7: 4.7uF; 0402
C2, C3, C14, C15: 12pF; 0402
C4, C11, C28: 100nF; 0402
C6, C9, C20, C21, C23, C27: 1uF; 0402
C8: 2.2uF; 0402
C10: 47nF; 0402
C12: 820pF; 0402
C13: 1pF; 0402
C16: 100pF; 0402
C17: 1.2pF; 0402
C22, C24: 10uF; 0402
D1: BLUE; 0402
D2: LED; 0402
J1: -; Pogo-pin-recepticle
J2: +; Pogo-pin-recepticle
L1: 10uH; 0402
L2: 15nH; 0402
L3: 4.7nH; 0402
L4: 2.2nH; 0402
Q1, Q2: NMOS-CSD17381F4; Mosfet0402
Q3, Q4, Q5: PMOS-CSD25483F4; Mosfet0402
R1: 10k; 0402
R2: 2M; 0402
R3, R11, R12: 1.5k; 0402
R4: 100K; 0402
R5: 1.1k; 0402
R6: 590; 0402
R7, R8: 0Ω; 0402
R9, R10: 4.7K; 0402
SW1: SW_Omron_B3FS; 16mmCompButton
TH1: 10K; 0402
U5: BQ27427; Texas_DSBGA-9_1.62mmx1.58mm_Layout3x3_P0.5mm
U6: nrf52833_qfn40; nrf52833
U8: Conn_01x14_Socket; FPC
U9: AS5600; SOIC-8-1EP_3.9x4.9mm_P1.27mm_EP2.514x3.2mm
U10: BQ24075RGT; VQFN-16-1EP_3x3mm_P0.5mm_EP1.6x1.6mm
U11: MIC5504; TDFN-4
X1: 32.768 kHz; Crystal_SMD_2012-2Pin_2.0x1.2mm
X2: 32MHZ; Crystal_SMD_2016-4Pin_2.0x1.6mm

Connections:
1.8V: C8.1, U5.B3 (VDD)
BLUE_LED: D1.2 (A), U6.31 (P0.03/AIN1)
Batteryin: U5.C3 (BAT), U8.10, U8.11
CE: R4.1, U10.4 (~CE)
D+: U6.13 (D+), U8.6
D-: U6.12 (D-), U8.8
FLEX_LED: R12.2, U6.34 (P0.29/AIN5)
GND: C1.1, C2.2, C3.2, C4.2, C5.2, C6.2, C7.1, C8.2, C9.2, C10.2, C11.2, C12.1, C13.1, C14.1, C15.1, C16.1, C17.1, C20.2, C21.2, C22.1, C23.2, C24.2, C27.2, C28.2, Q1.2 (S), Q2.2 (S), R1.1, R2.2, R3.1, R4.2, R5.2, R6.2, R7.1, R8.1, SW1.2, TH1.2, U5.B2 (VSS), U5.C1 (VSS), U6.25 (VSS), U6.37 (VSS), U6.41 (VSS), U8.2, U8.4, U8.5, U9.4 (GND), U9.5 (PGO), U10.8 (VSS), U10.14 (TMR), U10.15 (SYSOFF), U10.17 (VSS), U11.2 (GND), U11.5 (GND), X2.2, X2.4
GPOUT: U5.A1 (GPOUT)
MOS_EN: Q3.1 (G), R2.1, U6.7 (P0.11)
MOS_VDD: C27.1, C28.1, Q3.3 (D), R9.1, R10.2, U9.1 (VDD5V), U9.2 (VDD3V3)
unnamed: C17.2, L3.2, L4.1
unnamed: D1.1 (K), R3.2
unnamed: D2.1 (K), R11.2
unnamed: J1.1, Q1.3 (D), Q2.1 (G), Q4.3 (D), Q5.1 (G)
unnamed: J2.1, Q1.1 (G), Q2.3 (D), Q4.1 (G), Q5.3 (D)
unnamed: L1.1, L2.2
unnamed: R1.2, U5.B1 (BIN)
unnamed: C13.2, L3.1, U6.24 (ANT)
unnamed: L1.2, U6.39 (DCC)
unnamed: C4.1, U6.1 (DEC1)
unnamed: C16.2, U6.27 (DEC3)
unnamed: C9.1, C10.1, L2.1, U6.26 (DEC6), U6.38 (DEC4)
unnamed: C12.2, U6.21 (DEC5)
unnamed: C7.2, U6.11 (DECUSB)
unnamed: C2.1, U6.2 (P0.00/XL1), X1.1
unnamed: C3.1, U6.3 (P0.01/XL2), X1.2
unnamed: C15.2, U6.28 (XC1), X2.1
unnamed: C14.2, U6.29 (XC2), X2.3
unnamed: R12.1, U8.1
unnamed: R7.2, U10.6 (EN1)
unnamed: R8.2, U10.5 (EN2)
unnamed: R5.1, U10.12 (ILIM)
unnamed: R6.1, U10.16 (ISET)
unnamed: TH1.1, U10.1 (TS)
unnamed: R11.1, U10.9 (~CHG)
OUT: C20.1, C24.1, D2.2 (A), U10.10 (OUT), U10.11 (OUT), U11.3 (EN), U11.4 (VIN)
P0.15: R9.2, U5.A3 (SCL), U6.14 (P0.15), U9.7 (SCL)
P0.17: R10.1, U5.A2 (SDA), U6.15 (P0.17), U9.6 (SDA)
P0.20: U6.17 (P0.20)
P0.28: U6.33 (P0.28/AIN4)
P0.30: U6.35 (P0.30/AIN6)
P0.31: SW1.1, U6.36 (P0.31/AIN7)
RESET: U6.16 (P0.18/RESET)
VBUS: C5.1, C21.1, Q4.2 (S), Q5.2 (S), U6.10 (VBUS), U8.12, U8.13, U10.13 (IN)
VDD_nRF: C1.2, C6.1, C11.1, C23.1, Q3.2 (S), U6.8 (VDD), U6.9 (VDDH), U6.18 (VDD), U6.30 (VDD), U6.40 (VDD), U11.1 (VOUT)
antenna: L4.2, U8.3
int1: U6.6 (P1.09)
swc: U6.20 (SWDCLK), U8.7
swd: U6.19 (SWDIO), U8.9
vBAT: C22.2, U5.C2 (SRX), U10.2 (BAT), U10.3 (BAT)

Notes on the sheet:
Power path output
USB charge in
3V REGULATOR
0x55
Battery connection
charging Power input
USB input
System vout
Battery Connection
V_{f} < 3.0V
EXT VCC



Board: 4 copper layers, 19.9 x 19.5 mm, 59 parts (58 on the bottom side), 45 nets.

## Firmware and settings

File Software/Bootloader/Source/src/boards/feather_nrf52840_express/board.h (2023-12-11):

/*
 * The MIT License (MIT)
 *
 * Copyright (c) 2018 Ha Thach for Adafruit Industries
 *
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
 * THE SOFTWARE IS PROVIDED "AS IS", WITHOUT WARRANTY OF ANY KIND, EXPRESS OR
 * IMPLIED, INCLUDING BUT NOT LIMITED TO THE WARRANTIES OF MERCHANTABILITY,
 * FITNESS FOR A PARTICULAR PURPOSE AND NONINFRINGEMENT. IN NO EVENT SHALL THE
 * AUTHORS OR COPYRIGHT HOLDERS BE LIABLE FOR ANY CLAIM, DAMAGES OR OTHER
 * LIABILITY, WHETHER IN AN ACTION OF CONTRACT, TORT OR OTHERWISE, ARISING FROM,
 * OUT OF OR IN CONNECTION WITH THE SOFTWARE OR THE USE OR OTHER DEALINGS IN
 * THE SOFTWARE.
 */

#ifndef _FEATHER_NRF52840_H
#define _FEATHER_NRF52840_H

#define _PINNUM(port, pin)    ((port)*32 + (pin))

/*------------------------------------------------------------------*/
/* LED
 *------------------------------------------------------------------*/
#define LEDS_NUMBER           2
#define LED_PRIMARY_PIN       _PINNUM(1, 15)
#define LED_SECONDARY_PIN     _PINNUM(1, 10)
#define LED_STATE_ON          1

#define LED_NEOPIXEL          _PINNUM(0, 16)
#define NEOPIXELS_NUMBER      1
#define BOARD_RGB_BRIGHTNESS  0x040404

/*------------------------------------------------------------------*/
/* BUTTON
 *------------------------------------------------------------------*/
#define BUTTONS_NUMBER        2
#define BUTTON_1              _PINNUM(1, 02)
#define BUTTON_2              _PINNUM(0, 10)
#define BUTTON_PULL           NRF_GPIO_PIN_PULLUP

//--------------------------------------------------------------------+
// BLE OTA
//--------------------------------------------------------------------+
#define BLEDIS_MANUFACTURER   "Adafruit Industries"
#define BLEDIS_MODEL          "Feather nRF52840 Express"

//--------------------------------------------------------------------+
// USB
//--------------------------------------------------------------------+
#define USB_DESC_VID           0x239A
#define USB_DESC_UF2_PID       0x0029
#define USB_DESC_CDC_ONLY_PID  0x002A

//------------- UF2 -------------//
#define UF2_PRODUCT_NAME      "Adafruit Feather nRF52840 Express"
#define UF2_VOLUME_LABEL      "FTHR840BOOT"
#define UF2_BOARD_ID          "nRF52840-Feather-revD"
#define UF2_INDEX_URL         "https://www.adafruit.com/product/4062"

#endif // _FEATHER_NRF52840_H

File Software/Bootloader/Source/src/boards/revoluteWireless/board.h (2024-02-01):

#ifndef _REVOLUTE_WIRELESS_H
#define _REVOLUTE_WIRELESS_H

#define _PINNUM(port, pin)    ((port)*32 + (pin))

/*------------------------------------------------------------------*/
/* LED
 *------------------------------------------------------------------*/
#define LEDS_NUMBER       1
#define LED_PRIMARY_PIN   3 // Blue
#define LED_STATE_ON      1

//#define LED_NEOPIXEL          _PINNUM(0, 16)
//#define NEOPIXELS_NUMBER      1
//#define BOARD_RGB_BRIGHTNESS  0x040404

/*------------------------------------------------------------------*/
/* BUTTON
 *------------------------------------------------------------------*/
#define BUTTONS_NUMBER        2
#define BUTTON_1              28
#define BUTTON_2              18
#define BUTTON_PULL           NRF_GPIO_PIN_PULLUP

//--------------------------------------------------------------------+
// BLE OTA
//--------------------------------------------------------------------+
#define BLEDIS_MANUFACTURER   "Tongtong Inc"
#define BLEDIS_MODEL          "RevoluteWireless"

//--------------------------------------------------------------------+
// USB
//--------------------------------------------------------------------+
#define USB_DESC_VID           0x239A
#define USB_DESC_UF2_PID       0x0029 // TODO change later
#define USB_DESC_CDC_ONLY_PID  0x002A // TODO change later

//------------- UF2 -------------//
#define UF2_PRODUCT_NAME      "RevoluteWireless"
#define UF2_VOLUME_LABEL      "Revolute"
#define UF2_BOARD_ID          "RevoluteWireless-nrf52833"
#define UF2_INDEX_URL         "https://www.tongtonginc.com/revolute"

#endif

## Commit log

2022-10-10 Uploaded files
    Uploaded -PCB -3D Print -UF2 -Bootloader
    [Battery v2.step, Battery2 v1.step, Button.step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]
2023-05-05 updated to kicad 7
    [Revolute.kicad_pcb, Revolute.kicad_sch]
2023-05-05 version 2 base pcb
    [Revolute.kicad_pcb, Revolute.kicad_sch]
2023-05-05 Added V2 images, v2 pcb, v2 top pcb, v2 3d files
    [Ball_Bearing_Parametric v9 v6.obj, Base.stl, Cap.stl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]
2023-05-05 updated files
    [TopPCB.kicad_pcb]
2023-06-21 sorted files, added source code for v2
    [Battery v2.step, Battery2 v1.step, Button.step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]
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2023-06-24 app now emulates function of encoder
2023-06-24 app works but skips at high speed
    [main.c]
2023-06-28 updated pcb design
    [32MHZ Clock v1.step, Crystal 2 v0.step, Revolute.kicad_pcb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]
2023-06-28 made pcb smaller
    [Revolute.kicad_pcb]
2023-06-28 export step
    [revo.step]
2023-06-28 v2 magnet snapping update
    [Cap.stl, pcbtray.stl]
2023-07-05 3d files for all versions
    [Cap.stl, pcbtray.stl]
2023-07-08 got threads and semaphore working
2023-07-08 idents snap in middle of magnet
2023-11-20 git ignore, 3d files
    [Revolute-B_Cu.gbl, Revolute-B_Mask.gbs, Revolute-B_Paste.gbp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]
2023-11-27 modified 3d print files
    [Base.stl, Cap.stl, TopPCB.kicad_pcb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]
2023-11-27 updated gerbers
    [TopPCB-B_Cu.gbl, TopPCB-B_Mask.gbs, TopPCB-B_Paste.gbp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]
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2023-11-27 modified connector gerber
    [Revolute-B_Cu.gbl, Revolute-B_Mask.gbs, Revolute-B_Paste.gbp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]
2023-11-28 updated ibom
    [TopPCB.kicad_pcb, TopPCB.kicad_sch]
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2023-12-27 added revolute wireless(work in progress)
    [32MHZ Clock v1.step, Battery v2.step, Battery2 v1.step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]
2023-12-27 worked on wireless
    [BK13C06-10DP2-0.35V_3D_STP.stp, BK13C06-10DS2-0.35V_3D_STP.stp, Revolute.kicad_pcb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]
2023-12-28 added debug board (work in progress)
    [256Mbit GD25Q.step, 32MHZ Clock v1.step, APDS-9960.step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]
2023-12-29 worked on debugger, has to be flipped
    [BK13C06-10DP2-0.35V_3D_STP.stp, BK13C06-10DS2-0.35V_3D_STP.stp, NRF52832-CIAA-R.step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]
2023-12-30 finished debugger and wireless
    [SWDProgrammer.kicad_pcb, SWDProgrammer.kicad_sch]
2024-01-01 exported gerbers
    [Revolute-B_Cu.gbl, Revolute-B_Mask.gbs, Revolute-B_Paste.gbp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]
2024-01-02 update ibom
    [Revolute.kicad_pcb]
2024-01-02 changed via hole sizes
    [Revolute-B_Cu.gbl, Revolute-B_Mask.gbs, Revolute-B_Paste.gbp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]
2024-01-08 fixed problems on debugger
    [SWDProgrammer.kicad_pcb, SWDProgrammer.kicad_sch]
2024-01-13 fixed design
    [Revolute.kicad_pcb, Revolute.kicad_sch, SWDProgrammer.kicad_pcb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]
2024-01-14 added pogo charging pins, fixed debug connector
    [Revolute.kicad_pcb, Revolute.kicad_sch, SWDProgrammer.kicad_pcb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]
2024-01-25 fixed some non existant bugs
    [SWDProgrammer.kicad_pcb, SWDProgrammer.kicad_sch]
2024-01-25 updated gerbers and bom
    [Revolute-B_Cu.gbl, Revolute-B_Mask.gbs, Revolute-B_Paste.gbp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]
2024-02-01 fixed usb datapin issue
    [Revolute-B_Cu.gbl, Revolute-B_Mask.gbs, Revolute-B_Paste.gbp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]
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2024-02-02 worked on software, fixed wireless pcb power path circuit
    [Revolute.kicad_sch]
2024-02-03 fixed debugger datapin board, connected dir and out of as5600 to mcu
    [Revolute.kicad_pcb, Revolute.kicad_sch, SWDProgrammer.kicad_pcb]
2024-02-07 edited debugger board, generated new gerbers
    [256Mbit GD25Q.step, 32MHZ Clock v1.step, APDS-9960.step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]
2024-02-08 revised wireless design
    [Revolute.kicad_pcb]
2024-02-21 implemented 4button design
    [Revolute.kicad_pcb, Revolute.kicad_sch, button v4.step]
2024-02-24 new gerbers
    [Revolute-B_Cu.gbl, Revolute-B_Mask.gbs, Revolute-B_Paste.gbp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]
2024-02-24 revopod kikad files
    suck my dynamite dick
    [revopod1-B_Cu.gbl, revopod1-B_Mask.gbs, revopod1-B_Paste.gbp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]
2024-03-01 updated to kicad 8
    [Revolute.kicad_pcb, Revolute.kicad_sch]
2024-03-03 migrated debugger to kicad 8
    [SWDProgrammer.kicad_pcb]
2024-03-17 modified wireless PCB
    [Revolute.kicad_pcb, Revolute.kicad_sch]
2024-03-26 modified battery ground pad
    [Revolute.kicad_pcb]
2024-04-12 modified pcb files
    [Revolute.kicad_pcb]
2024-04-17 added testing pads to depricate fpc connector
    [Revolute.kicad_pcb]
2024-04-26 added ID column
    [Revolute.kicad_pcb, Revolute.kicad_sch, SWDProgrammer.kicad_pcb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]
2024-06-01 migrated components to 0201
    [BatteryBase.step, FPC ZIF.step, Revolute.kicad_pcb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]
2024-06-02 refined pcb
    [QFN_2016_4pins.STEP, Revolute.kicad_pcb, TDFN-4 v1.step]
2024-06-19 updated pcb 0201 components and flex battery attachment
    [Revolute.kicad_pcb, flex.kicad_pcb]
2024-06-19 new debugger
    [BatteryBase.step, FPC ZIF.step, QFN_2016_4pins.STEP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]
2024-07-27 current version
    [BK13C06-10DP2-0.35V_3D_STP.stp, BK13C06-10DS2-0.35V_3D_STP.stp, BatteryBase.step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]
2024-08-18 added gyro, flex pcb antenna
    [Revolute.kicad_pcb, Revolute.kicad_sch, SWDProgrammer.kicad_pcb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]
2024-09-15 revision 3, added mosfets for sensor power cutoff
    [CSD17381F4.STEP, Revolute.kicad_pcb, Revolute.kicad_sch]
2024-10-19 changed board shape, adedd unrouted test board, added active rectifier for reverse polarity, changed fuel gauge ic to smaller
    [Revolute.kicad_pcb, Revolute.kicad_sch, Revolutetestboard.kicad_pcb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]
2024-12-27 new flex and new pcbs
    [Revolute production.kicad_pcb, Revolute production.kicad_sch, Revolute.kicad_pcb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]
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2024-12-29 added jlink adapter
    [jlink adapter.kicad_pcb]
2024-12-29 added status led
    [Revolute production.kicad_pcb, Revolute production.kicad_sch, flex3kicad_pcb.kicad_pcb]
2025-02-14 revolute production boards
    [256Mbit GD25Q.step, 32MHZ Clock v1.step, APDS-9960.step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]
2025-02-17 unrouted test board
    [Revolutetestboard.kicad_pcb, Revolutetestboard.kicad_sch, dbg.kicad_sch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]
2025-02-17 added copper zone keep out for antenna
    [Revolutetestboard.kicad_pcb]
2025-02-17 remove non test board files
    [256Mbit GD25Q.step, 32MHZ Clock v1.step, APDS-9960.step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]
2025-02-17 removed more files
    [Revolute.kicad_pcb, Revolute.kicad_sch, dbg.kicad_sch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]
2025-02-17 routing session 1
    [Revolutetestboard.kicad_pcb, dbg.kicad_sch, freerouting.dsn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]
2025-02-21 added TLV493D sensor
    [rev.kicad_sch]
2025-02-21 new route
    [Revolutetestboard.kicad_pcb]
2025-02-21 added some zones
    [Revolutetestboard.kicad_pcb]
2025-02-22 test board done
    [Revolutetestboard.kicad_pcb, pod.kicad_sch]
2025-02-24 finished routing
    [Revolutetestboard.kicad_pcb, pod.kicad_sch, rev.kicad_sch]
2025-02-25 centered flex pcb, made pcb 1.6mm
    [Revolutetestboard.kicad_pcb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]
2025-02-27 added files back
    [256Mbit GD25Q.step, 32MHZ Clock v1.step, APDS-9960.step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]
2025-03-11 update kicad 9
    [Revolutetestboard.kicad_pcb, Revolutetestboard.kicad_sch, dbg.kicad_sch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]
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
